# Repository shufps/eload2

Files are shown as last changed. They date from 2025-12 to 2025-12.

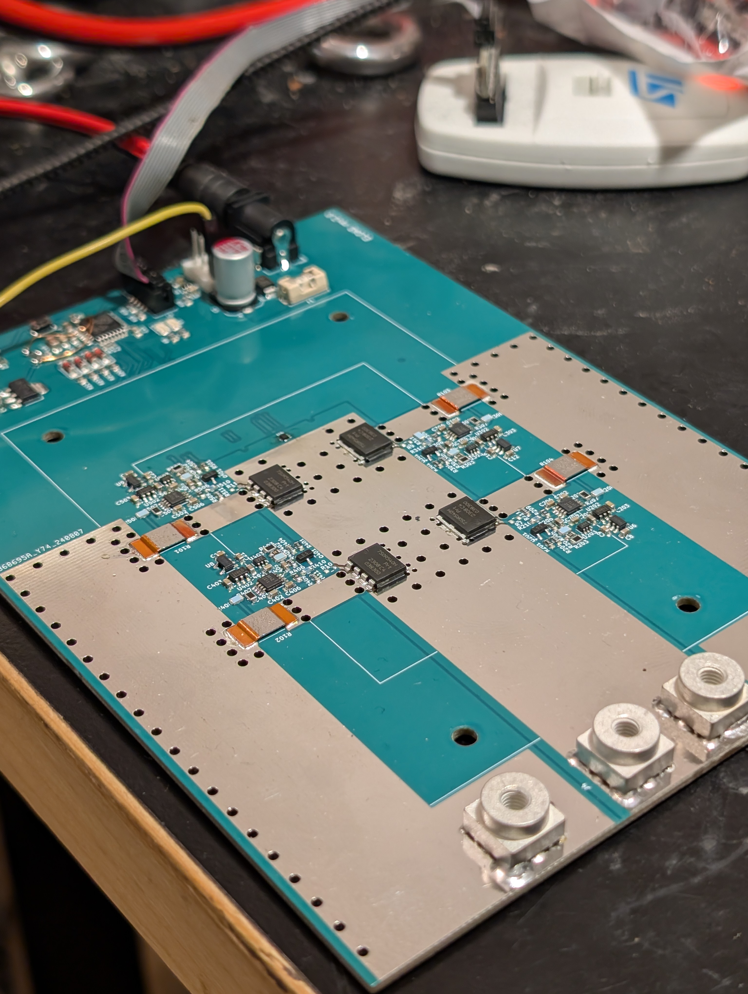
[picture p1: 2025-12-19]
images/PXL_20251215_150642152.jpg

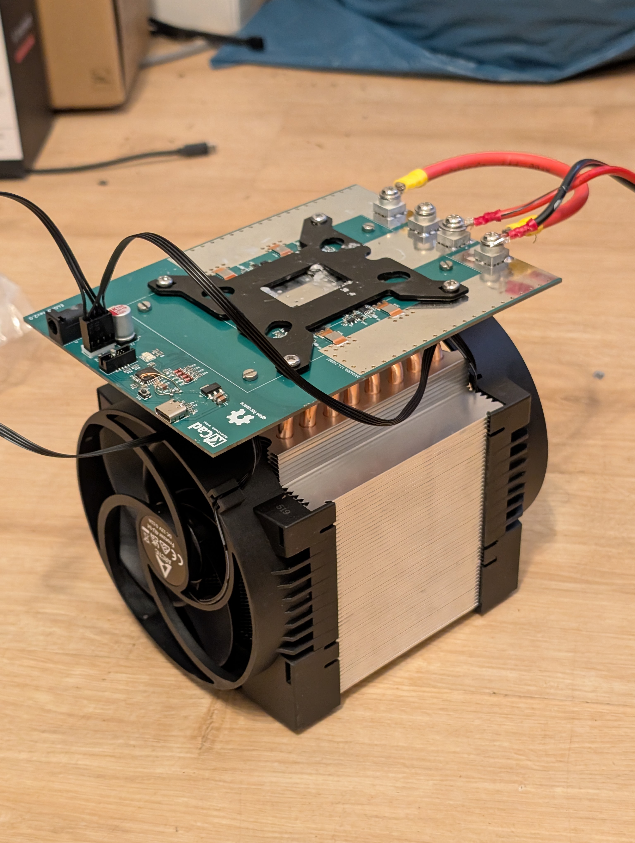
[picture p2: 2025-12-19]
images/PXL_20251219_101324146.jpg

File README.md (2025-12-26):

> ⚠️ **Disclaimer / Status**
>
> This project is provided **AS IS**, **without any warranty** and **without any kind of support**.
> Use at your own risk — this is **high-current / high-power** hardware and can damage equipment or cause injury if used incorrectly.

# eload2 (Load v2)





A compact, over-engineered **multi-channel electronic load** for **low-voltage / high-current** testing — built because nothing affordable exists that does *0–1.5V @ ~100A* properly.

No display. Control via **USB** from a PC (Python), firmware on **STM32**.

## Why this exists

I needed a tool to:
- test **buck converters / VRMs** in the **0–1.5V** range at serious currents
- still be usable as a “normal” load at **12V** (e.g. for power supplies / battery projects)
- be stable, repeatable and boring (in the good sense)

Commercial options in this niche are either impractical or unreasonably expensive — so I built it.

## Highlights

- **4 independent channels**
- Designed for:
  - **0–1.5V** VRM / buck testing up to **~100A** total (depending on cooling & SOA)
  - **12V** testing (e.g. ~8–12A, depending on dissipation)
- Each channel has its own analog supply chain (low coupling, predictable behavior):
  - dedicated **9V LDO**
  - dedicated precision **reference** (REF3433)
  - dedicated **16-bit DAC**
  - dedicated **OPA2196** control loop
  - dedicated MOSFET “arm”
- MOSFETs: **BUK7S0R5-40HJ** (very low Rds(on), beefy SOA)
- Cooling: **SP3/TR4 CPU cooler** (tested in practice)
- High-current IO: **M4** power connections (aiming for ~80A per connector)
- PCB: **120 × 160 mm**, **4-layer**, 1oz/1oz
  (large copper, parallel layers, big via arrays; optional copper busbars)

## Status

- PCBs + stencil: ✅
- Parts: ✅ (BOM originally ~1.5 years old, most parts still available)
- Bring-up: ✅
- Verified load test: **12V @ 10A (120W) for ~15 min → ~55°C board temperature** (with the big cooler)

## Errata

- Current setting is a little bit off. For example 11.5A needs to be set for 10.0A current.

## Minimalistic Web UI

There is a minimalistic web UI.



It can be run using `streamlit`:
```bash
streamlit run eload_ui.py
```

## Documentation

https://www.mikrocontroller.net/topic/563073

## Repository structure (typical)

- `kicad/` – schematics, PCB, mechanical notes
- `firmware/` – STM32 firmware (Rust, Embassy)
- `python/` – PC tooling / scripts (Python)

## Quick start

### Firmware
- Build/flash using your usual STM32 + Rust toolchain.
- This project uses **Embassy** async tasks.

### Host control
- Connect the board via USB.
- Use the Python scripts to set:
  - per-channel DAC setpoints
  - PWM / fan / enable (depending on build)
  - read back telemetry (if enabled)

## Safety / Notes

This is a **high current** design.
- Use short, thick wiring for low-voltage/high-current tests.
- Treat every milliohm as a heater.
- Ensure solid cooling and stable mounting before sustained high power tests.
- If you don’t know what you’re doing: don’t connect this to expensive hardware.

## License

CERN-OHL-S: https://ohwr.org/cern_ohl_s_v2.pdf

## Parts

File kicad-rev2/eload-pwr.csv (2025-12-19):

Reference | Value | Footprint | Qty | DNP | Distributor | Manufacturer | OrderNr
C1,C202,C204,C302,C304,C402,C404,C502,C504 | 100n | Capacitor_SMD:C_0603_1608Metric | 9
C2 | 330µ | Capacitor_SMD:CP_Elec_8x10 | 1 |  | D | A768KS337M1ELAE019 | 399-A768KS337M1ELAE019CT-ND
C3,C4,C15,C20 | 10µ/50V | Capacitor_SMD:C_1206_3216Metric | 4
C5,C14,C18,C19 | 1µ | Capacitor_SMD:C_0805_2012Metric | 4
C8,C9,C12,C16,C17,C21,C22,C23,C201,C205,C301,C305,C401,C405,C501,C505 | 1µ | Capacitor_SMD:C_0603_1608Metric | 16
C10,C11,C13 | 100n | Capacitor_SMD:C_0805_2012Metric | 3
C203,C303,C403,C503 | 10µ | Capacitor_SMD:C_0603_1608Metric | 4
C206,C306,C406,C506 | 10n | Capacitor_SMD:C_0603_1608Metric | 4
D1 | SMBJ12A | Diode_SMD:D_SMB | 1 |  | D | SMBJ12A | SMBJ12ALFCT-ND
D2,D6,D7,D8,D9 | 3.3V | Diode_SMD:D_MiniMELF | 5 |  | D | BZV55-C3V6,115 | 1727-3631-1-ND
D4 | LED | LED_SMD:LED_1206_3216Metric | 1
F1 | 0.5A | myfootprints:fuseholder_littlefuse_blok | 1 |  | D | 0154.500DR | F1220CT-ND
J1 | Barrel_Jack_Switch | Connector_BarrelJack:BarrelJack_CUI_PJ-102AH_Horizontal | 1 |  | D | PJ-102AH | CP-102AH-ND
J2 | USB_C_Receptacle_USB2.0 | Connector_USB:USB_C_Receptacle_GCT_USB4105-xx-A_16P_TopMnt_Horizontal | 1 |  | D | USB4105-GF-A | 2073-USB4105-GF-ACT-ND
J3 | SWD | myfootprints:PinHeader_IDC_2x05_P1.27mm_Vertical_SMD | 1 |  | X
J4,J5,J6,J7 | Conn_01x01 | TerminalBlock_Wuerth:Wuerth_REDCUBE-THR_WP-THRBU_74650194_THR | 4 |  | D | 74650194R | 732-74650194RCT-ND
M1 | Fan_4pin | Connector:FanPinHeader_1x04_P2.54mm_Vertical | 1 |  | D | 0470531000 | WM4330-ND
Q101,Q102,Q103,Q104 | NMOS | myfootprints:LFPAK88-SOT1235 | 4 |  | D | BUK7S0R5-40HJ | 1727-BUK7S0R5-40HJCT-ND
Q201,Q301,Q401,Q501 | BSS138 | Package_TO_SOT_SMD:SOT-23 | 4 |  | D | BSS138 | 4530-BSS138CT-ND
R1,R2 | 5.1k | Resistor_SMD:R_0805_2012Metric | 2
R3,R4,R14 | 22 | Resistor_SMD:R_0805_2012Metric | 3
R5 | 100k | Resistor_SMD:R_0805_2012Metric | 1
R6,R18 | 3.3k | Resistor_SMD:R_0805_2012Metric | 2
R7,R9,R10,R11 | 100k | Resistor_SMD:R_0603_1608Metric | 4
R8 | 560 | Resistor_SMD:R_0805_2012Metric | 1
R12,R15,R16,R17 | 10k | Resistor_SMD:R_0805_2012Metric | 4
R13 | 33k | Resistor_SMD:R_0805_2012Metric | 1
R19 | 2.7k | Resistor_SMD:R_0805_2012Metric | 1
R20,R21,R22,R23 | 1.5k | Resistor_SMD:R_0805_2012Metric | 4
R101,R102,R103,R104 | 4m/4W/0.5% | myfootprints:R3920 | 4 |  | D | SEWF3920D4L00P9 | 4506-SEWF3920D4L00P9CT-ND
R201,R301,R401,R501 | 17.4k | Resistor_SMD:R_0603_1608Metric | 4
R202,R302,R402,R502 | 10k | Resistor_SMD:R_0603_1608Metric | 4
R203,R207,R303,R307,R403,R407,R503,R507 | 31.6k/0.1% | Resistor_SMD:R_0603_1608Metric | 8 |  | D | RG2012P-3162-B-T5 | RG20P31.6KBCT-ND
R204,R206,R211,R304,R306,R311,R404,R406,R411,R504,R506,R511 | 1k | Resistor_SMD:R_0603_1608Metric | 12
R205,R208,R305,R308,R405,R408,R505,R508 | 1k/0.1% | Resistor_SMD:R_0603_1608Metric | 8 |  | D | RG2012P-102-B-T5 | RG20P1.0KBCT-ND
R209,R309,R409,R509 | 0R | Resistor_SMD:R_0603_1608Metric | 4
R210,R310,R410,R510 | 100 | Resistor_SMD:R_0603_1608Metric | 4
SW1 | boot | Button_Switch_SMD:SW_Push_1P1T_NO_CK_KMR2 | 1 |  | D | KMR231NG ULC LFS | CKN10284CT-ND
U1 | LM1117-3.3 | Package_TO_SOT_SMD:SOT-223-3_TabPin2 | 1 |  | D | LM1117MPX-33NOPB | 488-LM1117MPX-33NOPBCT-ND
U2 | STM32L072KZT6 | Package_QFP:LQFP-32_7x7mm_P0.8mm | 1 |  | D | STM32L072KZT6 | 497-19668-ND
U4 | TMP1075 | myfootprints:TMP1075-DRL | 1 |  | D | TMP1075NDRLR | 296-TMP1075NDRLRCT-ND
U5 | TXU0101 | Package_TO_SOT_SMD:SOT-363_SC-70-6 | 1 |  | D | TXU0101DCKR | 296-TXU0101DCKRCT-ND
U6,U7,U8,U9 | R1154N090B | Package_TO_SOT_SMD:SOT-23-5 | 4 |  | D | R1154N090B-TR-FE | 2129-R1154N090B-TR-FECT-ND
U201,U301,U401,U501 | OPA2196IDGKT | Package_SO:VSSOP-8_3.0x3.0mm_P0.65mm | 4 |  | D | OPA2196IDGKT | 296-48158-1-ND
U202,U302,U402,U502 | REF3433IDBVR | Package_TO_SOT_SMD:SOT-23-6 | 4 |  | D | REF3433IDBVR | 296-49859-1-ND
U203,U303,U403,U503 | DAC8411IDCKR | Package_TO_SOT_SMD:SOT-363_SC-70-6 | 4 |  | D | DAC8411IDCKR | 296-DAC8411IDCKRCT-ND

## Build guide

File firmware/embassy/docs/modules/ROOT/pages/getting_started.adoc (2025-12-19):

= Getting started

So you want to try Embassy, great! To get started, there are a few tools you need to install:

* link:https://rustup.rs/[rustup] - the Rust toolchain is needed to compile Rust code.
* link:https://crates.io/crates/probe-rs[probe-rs] - to flash the firmware on your device. If you already have other tools like `OpenOCD` setup, you can use that as well.

If you don't have any supported board, don't worry: you can also run embassy on your PC using the `std` examples.

== Getting a board with examples

Embassy supports many microcontroller families, but the quickest way to get started is by using a board which Embassy has existing example code for.

This list is non-exhaustive. If your board isn’t included here, check the link:https://github.com/embassy-rs/embassy/tree/main/examples[examples folder] to see if example code has been written for it.

=== nRF kits

* link:https://www.nordicsemi.com/Products/Development-hardware/nrf52-dk[nRF52 DK]
* link:https://www.nordicsemi.com/Products/Development-hardware/nRF9160-DK[nRF9160 DK]

=== STM32 kits

* link:https://www.st.com/en/evaluation-tools/nucleo-h743zi.html[STM32 Nucleo-144 development board with STM32H743ZI MCU]
* link:https://www.st.com/en/evaluation-tools/nucleo-f429zi.html[STM32 Nucleo-144 development board with STM32F429ZI MCU]
* link:https://www.st.com/en/evaluation-tools/b-l4s5i-iot01a.html[STM32L4+ Discovery kit IoT node, low-power wireless, BLE, NFC, WiFi]
* link:https://www.st.com/en/evaluation-tools/b-l072z-lrwan1.html[STM32L0 Discovery kit LoRa, Sigfox, low-power wireless]
* link:https://www.st.com/en/evaluation-tools/nucleo-wl55jc.html[STM32 Nucleo-64 development board with STM32WL55JCI MCU]
* link:https://www.st.com/en/evaluation-tools/b-u585i-iot02a.html[Discovery kit for IoT node with STM32U5 series]

=== RP2040 kits

* link:https://www.raspberrypi.com/products/raspberry-pi-pico/[Raspberry Pi Pico]

=== ESP32

* link:https://github.com/esp-rs/esp-rust-board[ESP32C3]

== Running an example

First you need to clone the link:https://github.com/embassy-rs/embassy[github repository];

[source, bash]
----
git clone https://github.com/embassy-rs/embassy.git
cd embassy
----

Once you have a copy of the repository, find examples folder for your board and, and build an example program. `blinky` is a good choice as all it does is blink an LED – the embedded world’s equivalent of “Hello World”.

[source, bash]
----
cd examples/nrf52840
cargo build --bin blinky --release
----

Once you’ve confirmed you can build the example, connect your computer to your board with a debug probe and run it on hardware:

[source, bash]
----
cargo run --bin blinky --release
----

If everything worked correctly, you should see a blinking LED on your board, and debug output similar to this on your computer:

[source]
----
    Finished dev [unoptimized + debuginfo] target(s) in 1m 56s
     Running `probe-run --chip STM32F407VGTx target/thumbv7em-none-eabi/debug/blinky`
(HOST) INFO  flashing program (71.36 KiB)
(HOST) INFO  success!
────────────────────────────────────────────────────────────────────────────────
0 INFO  Hello World!
└─ blinky::__embassy_main::task::{generator#0} @ src/bin/blinky.rs:18
1 INFO  high
└─ blinky::__embassy_main::task::{generator#0} @ src/bin/blinky.rs:23
2 INFO  low
└─ blinky::__embassy_main::task::{generator#0} @ src/bin/blinky.rs:27
3 INFO  high
└─ blinky::__embassy_main::task::{generator#0} @ src/bin/blinky.rs:23
4 INFO  low
└─ blinky::__embassy_main::task::{generator#0} @ src/bin/blinky.rs:27
----

NOTE: How does the `cargo run` command know how to connect to our board and program it? In each `examples` folder, there’s a `.cargo/config.toml` file which tells cargo to use link:https://probe.rs/[probe-rs] as the runner for ARM binaries in that folder. probe-rs handles communication with the debug probe and MCU. In order for this to work, probe-rs needs to know which chip it’s programming, so you’ll have to edit this file if you want to run examples on other chips.

=== It didn’t work!

If you hare having issues when running `cargo run --release`, please check the following:

* You are specifying the correct `--chip` on the command line, OR
* You have set `.cargo/config.toml`'s run line to the correct chip, AND
* You have changed `examples/Cargo.toml`'s HAL (e.g. embassy-stm32) dependency's feature to use the correct chip (replace the existing stm32xxxx feature)

At this point the project should run. If you do not see a blinky LED for blinky, for example, be sure to check the code is toggling your board's LED pin.

If you are trying to run an example with `cargo run --release` and you see the following output:
[source]
----
0.000000 INFO Hello World!
└─ <invalid location: defmt frame-index: 14>
0.000000 DEBUG rcc: Clocks { sys: Hertz(80000000), apb1: Hertz(80000000), apb1_tim: Hertz(80000000), apb2: Hertz(80000000), apb2_tim: Hertz(80000000), ahb1: Hertz(80000000), ahb2: Hertz(80000000), ahb3: Hertz(80000000) }
└─ <invalid location: defmt frame-index: 124>
0.000061 TRACE allocating type=Interrupt mps=8 interval_ms=255, dir=In
└─ <invalid location: defmt frame-index: 68>
0.000091 TRACE   index=1
└─ <invalid location: defmt frame-index: 72>
----

To get rid of the frame-index error add the following to your `Cargo.toml`:

[source,toml]
----
[profile.release]
debug = 2
----

If you’re still having problems, check the link:https://embassy.dev/book/dev/faq.html[FAQ], or ask for help in the link:https://matrix.to/#/#embassy-rs:matrix.org[Embassy Chat Room].

== What's next?

Congratulations, you have your first Embassy application running! Here are some suggestions for where to go from here:

* Read more about the xref:runtime.adoc[executor].
* Read more about the xref:hal.adoc[HAL].
* Start xref:basic_application.adoc[writing your application].

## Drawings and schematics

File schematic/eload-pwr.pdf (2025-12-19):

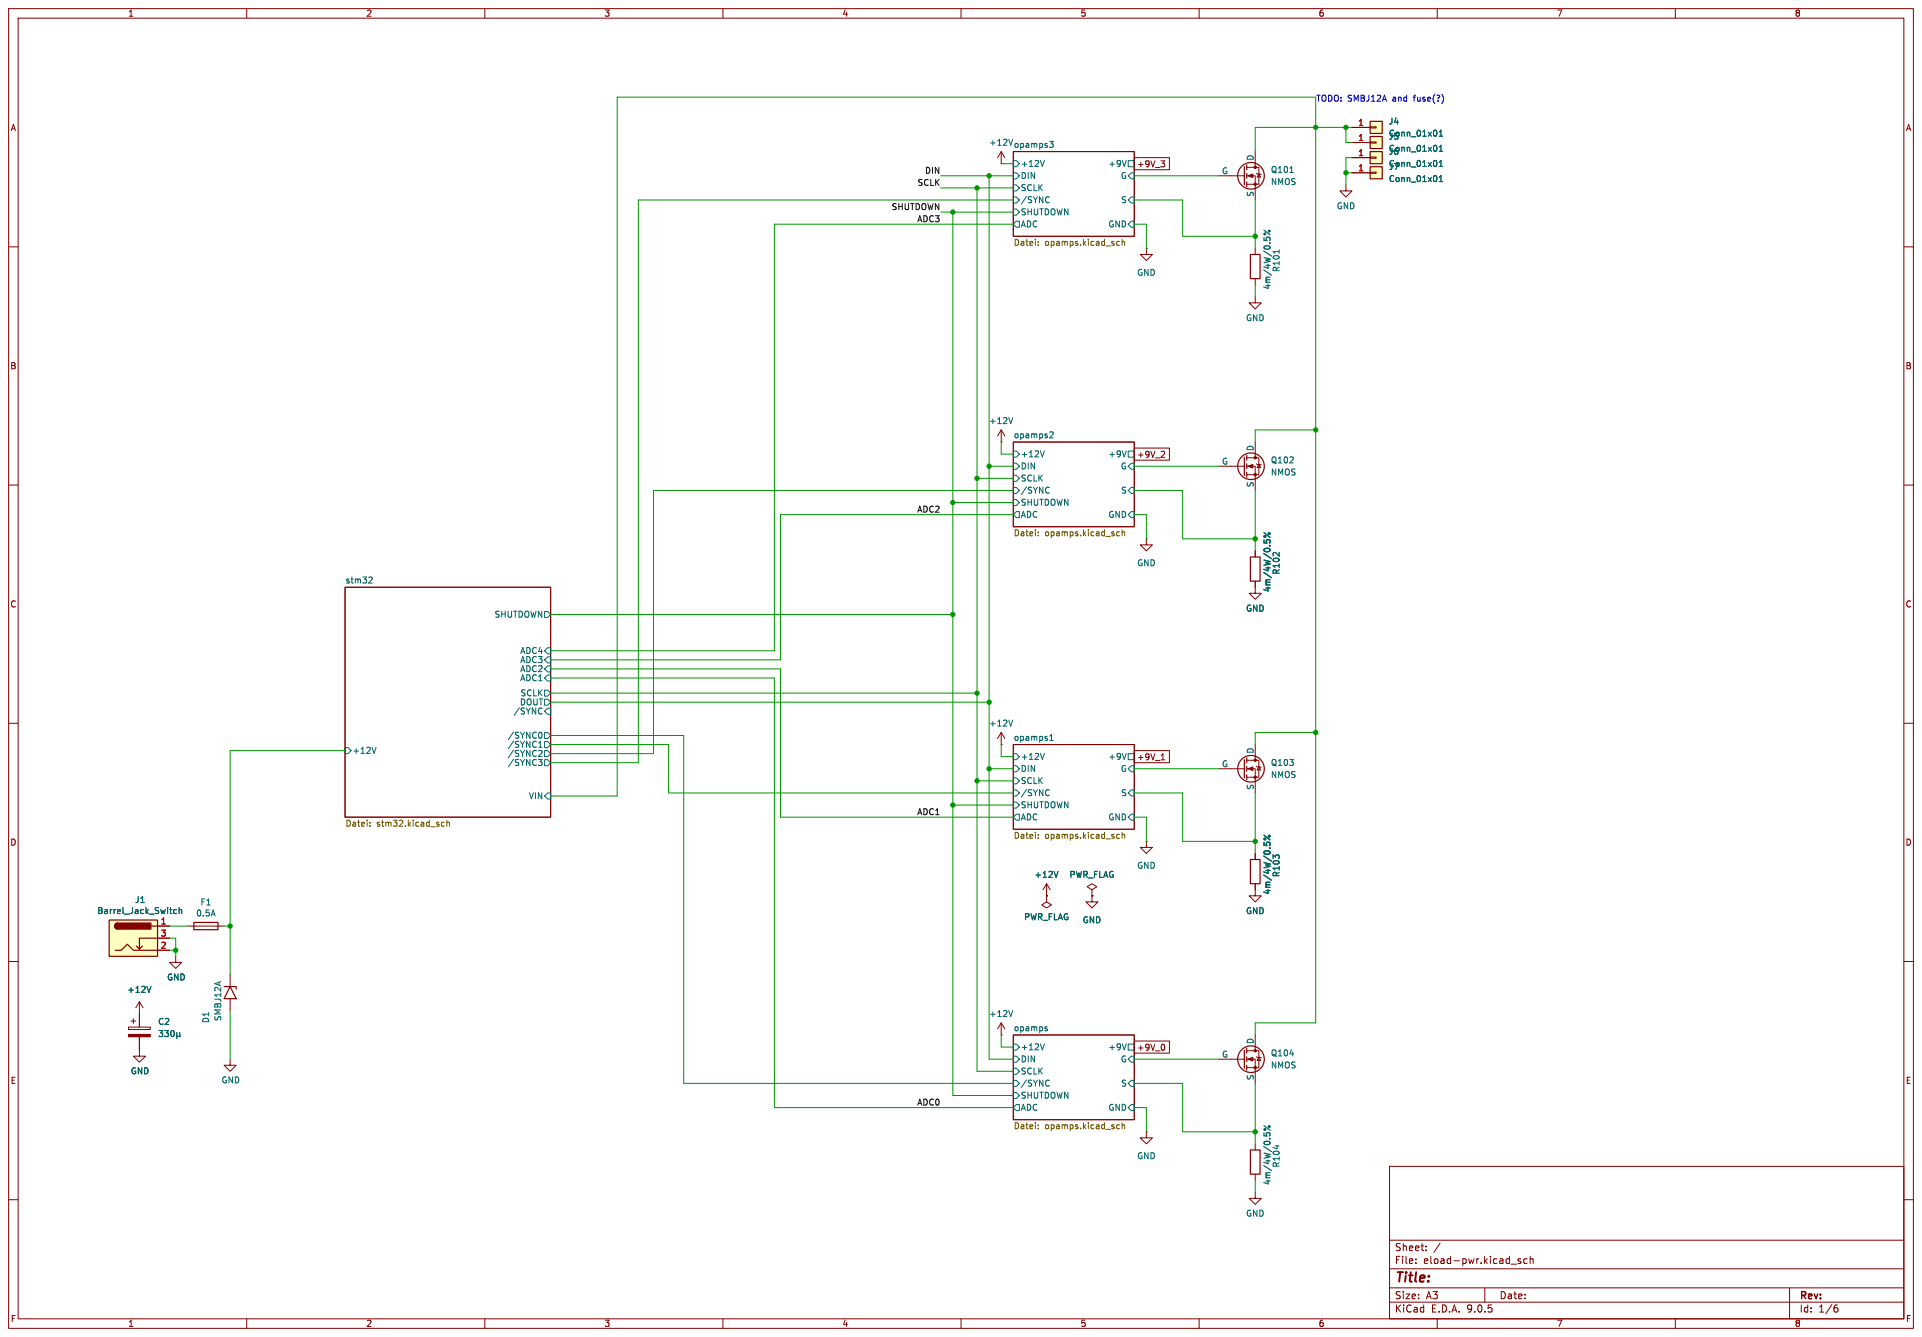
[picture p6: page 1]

Id: 1/6 Title: File: eload-pwr.kicad_sch Sheet: /

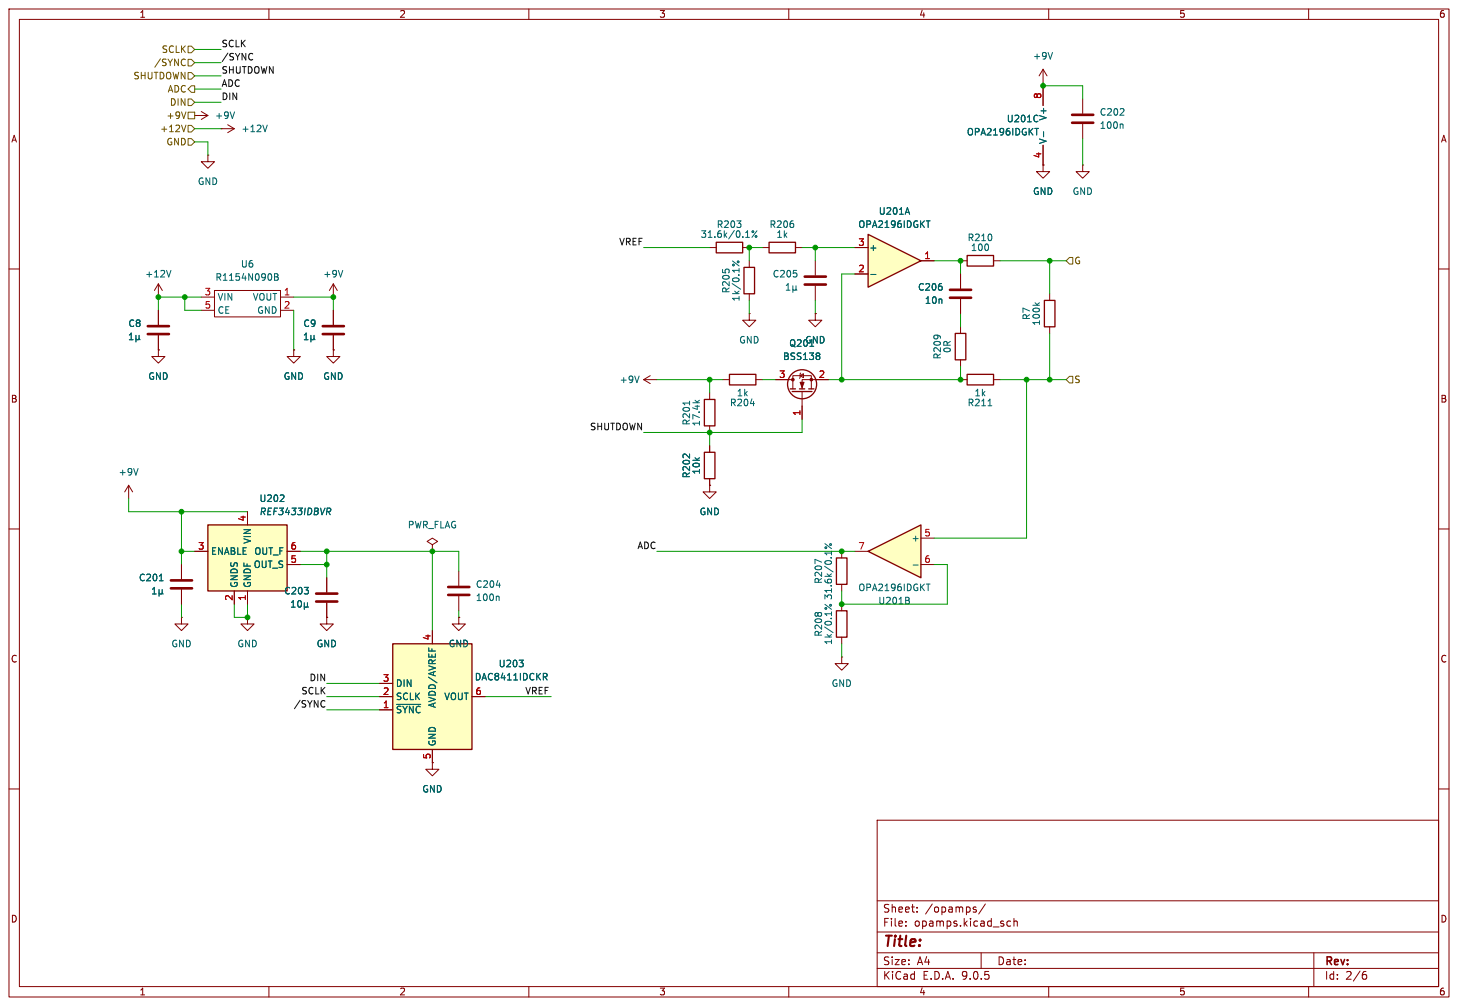
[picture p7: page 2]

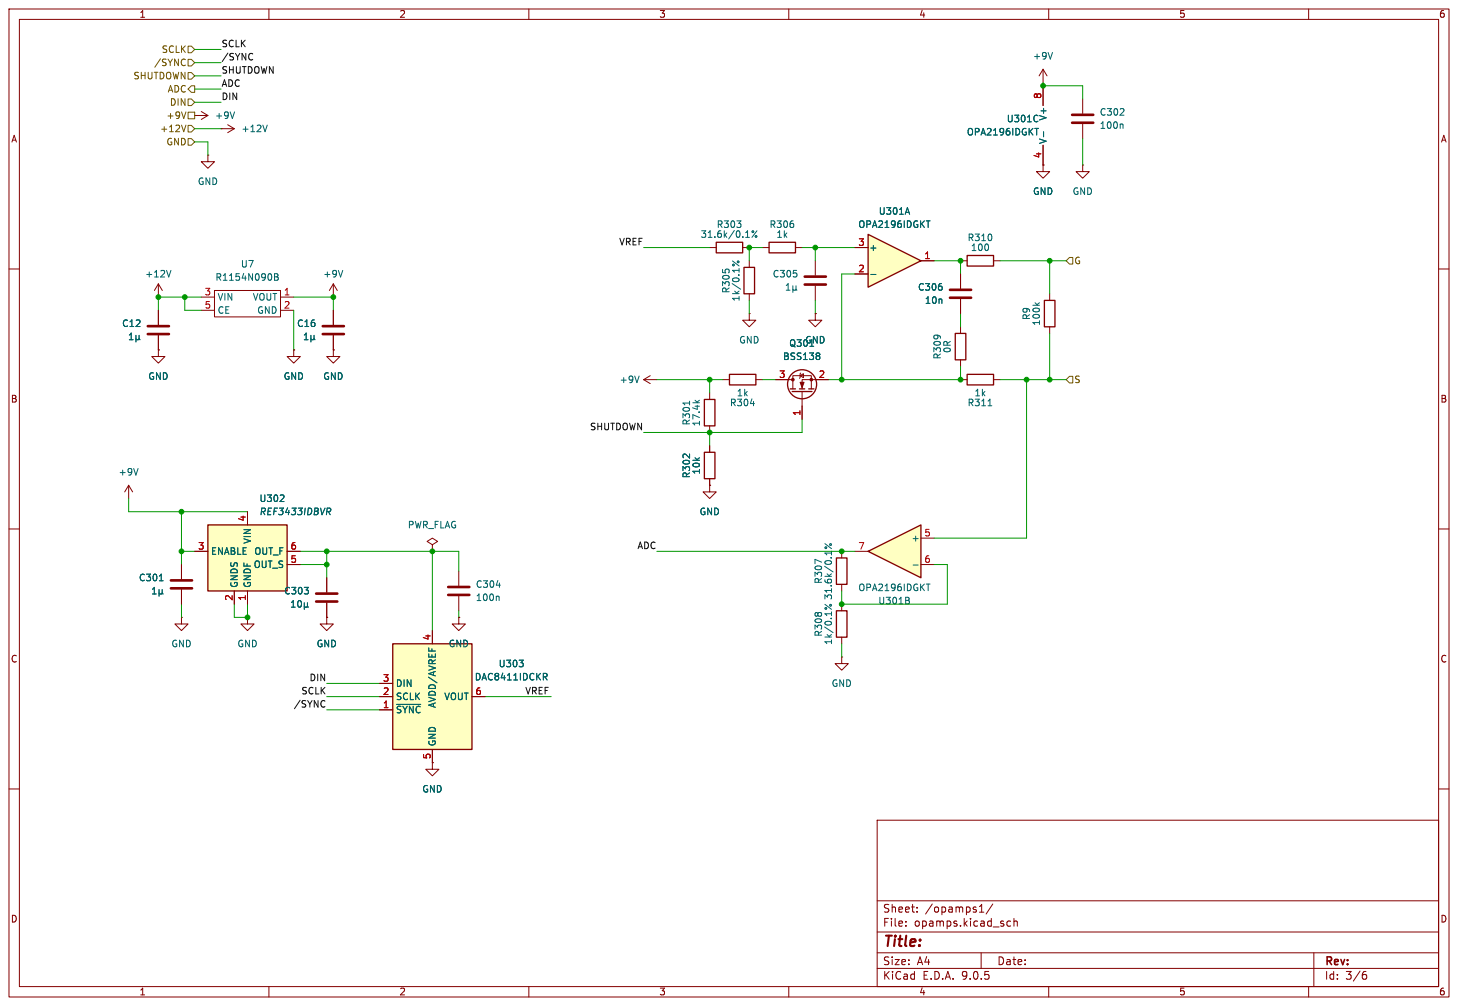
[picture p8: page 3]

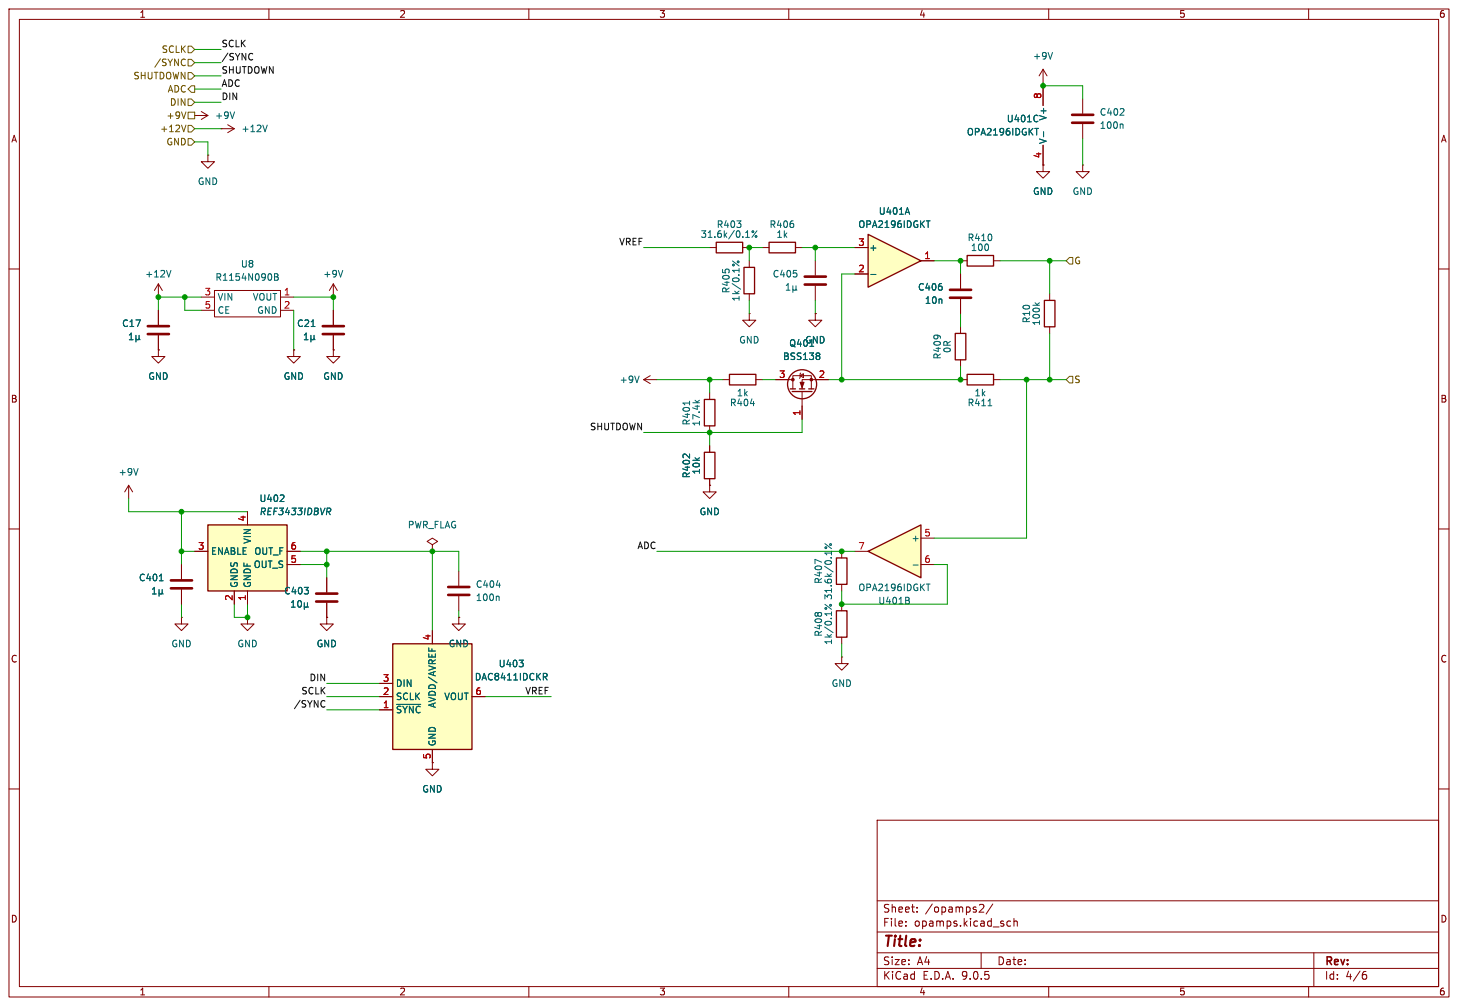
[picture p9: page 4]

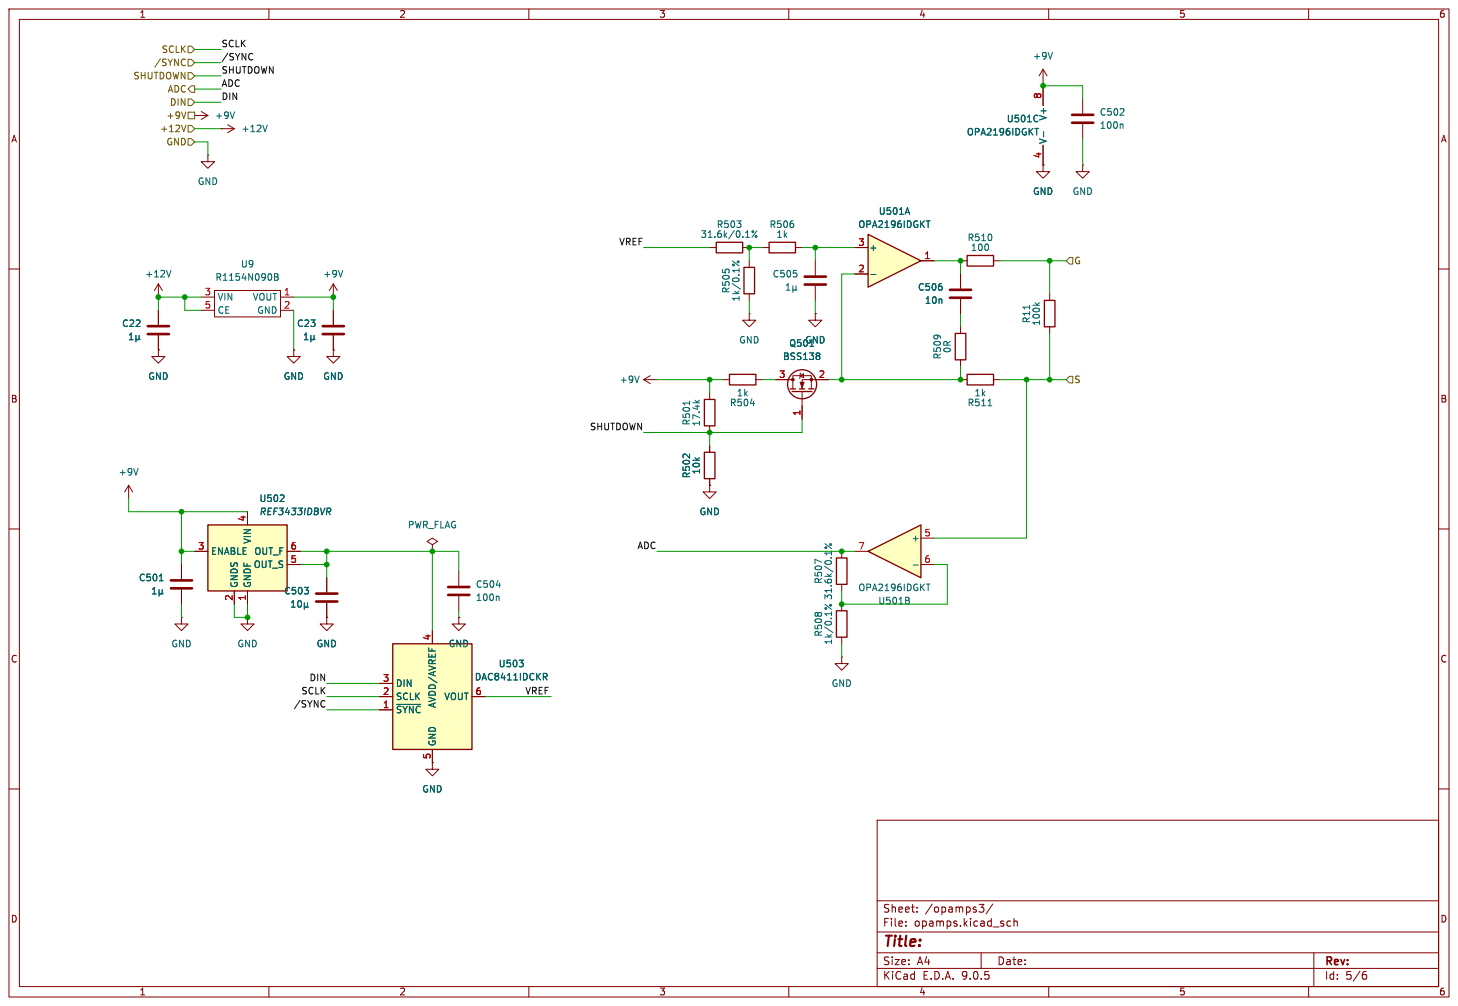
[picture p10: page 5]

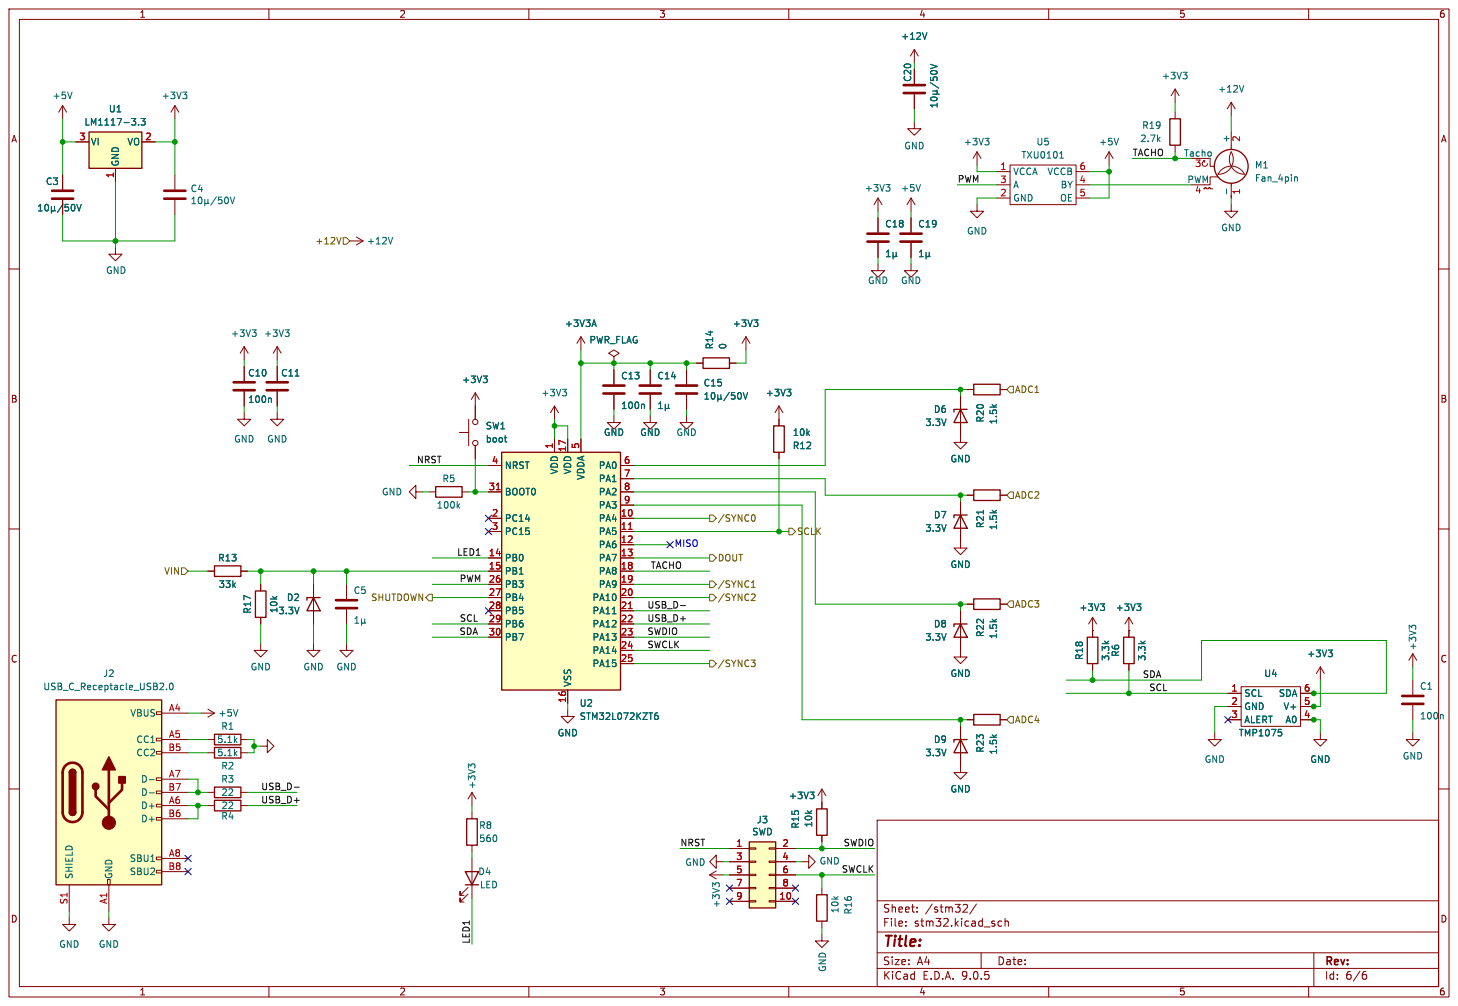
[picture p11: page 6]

Id: 6/6 Title: File: stm32.kicad_sch Sheet: /stm32/ D8

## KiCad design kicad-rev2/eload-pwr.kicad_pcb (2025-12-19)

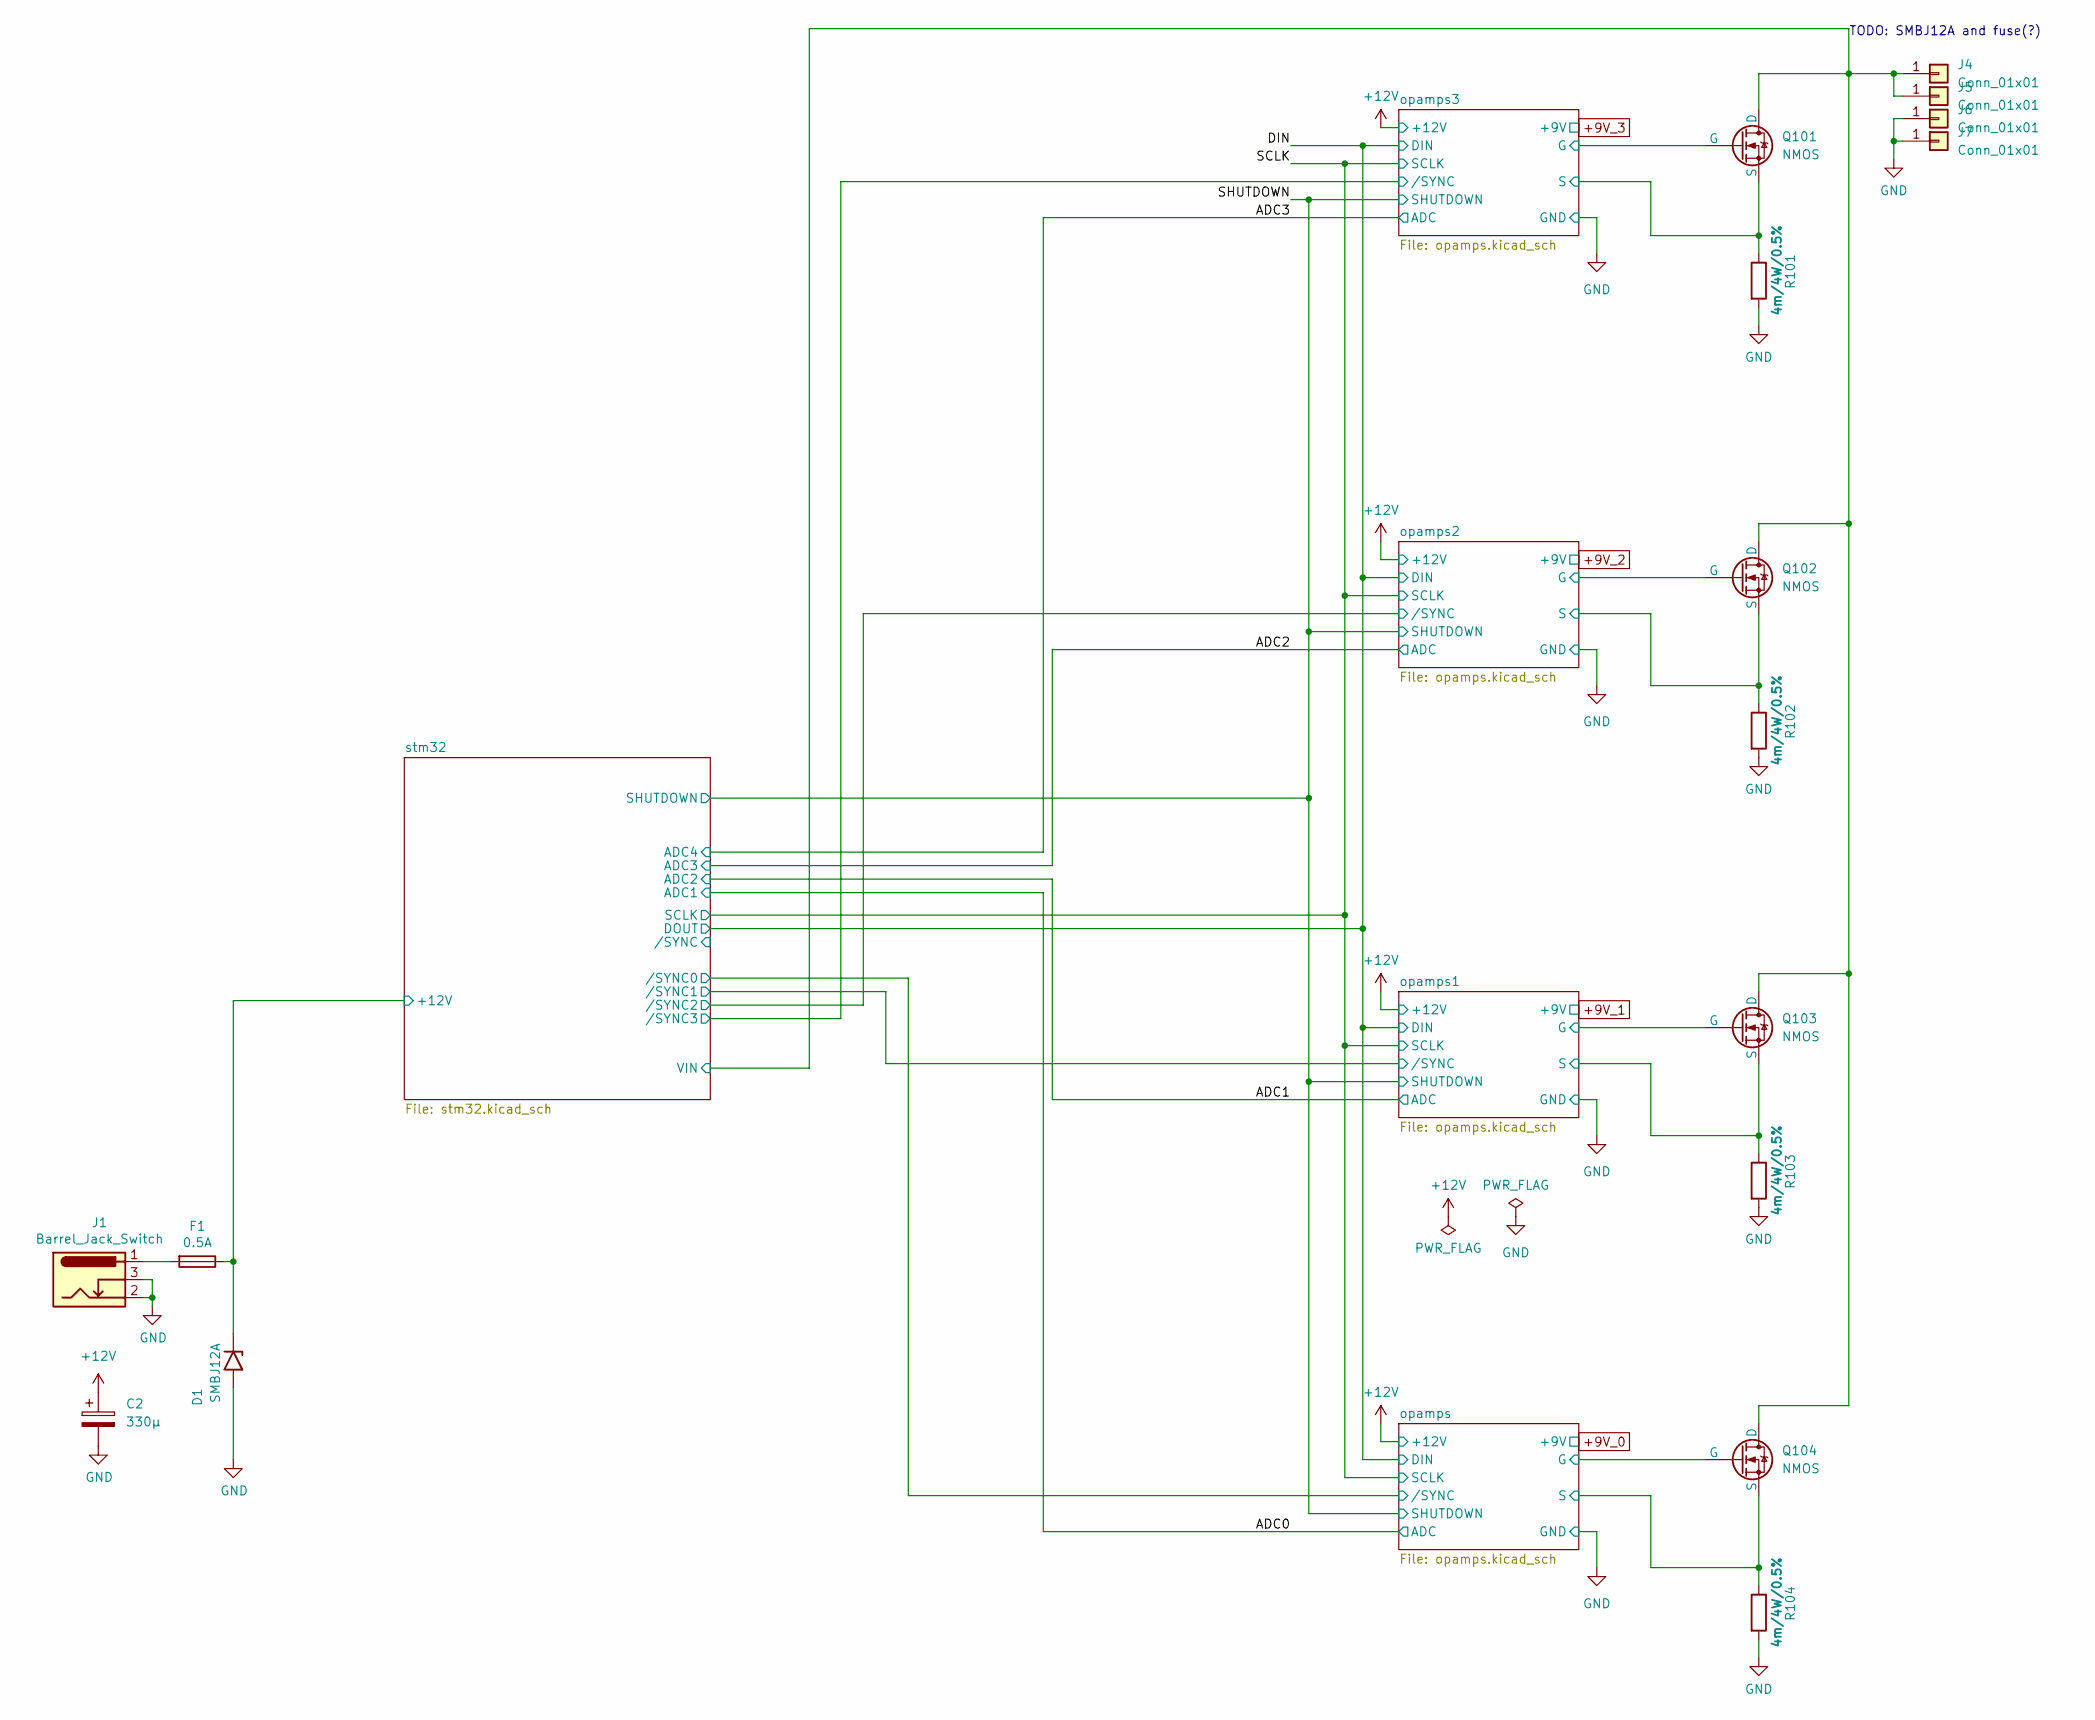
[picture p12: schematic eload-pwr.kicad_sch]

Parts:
C2: 330µ; CP_Elec_8x10
D1: SMBJ12A; D_SMB
F1: 0.5A; fuseholder_littlefuse_blok
J1: Barrel_Jack_Switch; BarrelJack_CUI_PJ-102AH_Horizontal
J4, J5, J6, J7: Conn_01x01; Wuerth_REDCUBE-THR_WP-THRBU_74650194_THR
Q101, Q102, Q103, Q104: NMOS; LFPAK88-SOT1235
R101, R102, R103, R104: 4m/4W/0.5%; R3920

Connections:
+12V: C2.1, D1.1 (A1), F1.1; also elsewhere on the board
/opamps1/G: Q103.G; also elsewhere on the board
/opamps1/S: Q103.S, R103.1; also elsewhere on the board
/opamps2/G: Q102.G; also elsewhere on the board
/opamps2/S: Q102.S, R102.1; also elsewhere on the board
/opamps3/G: Q101.G; also elsewhere on the board
/opamps3/S: Q101.S, R101.1; also elsewhere on the board
/opamps/G: Q104.G; also elsewhere on the board
/opamps/S: Q104.S, R104.1; also elsewhere on the board
/stm32/VIN: J4.1, J5.1, Q101.D, Q102.D, Q103.D, Q104.D; also elsewhere on the board
GND: C2.2, D1.2 (A2), J1.2, J1.3, J6.1, J7.1, R101.2, R102.2, R103.2, R104.2; also elsewhere on the board
unnamed: F1.2, J1.1

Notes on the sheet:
TODO: SMBJ12A and fuse(?)

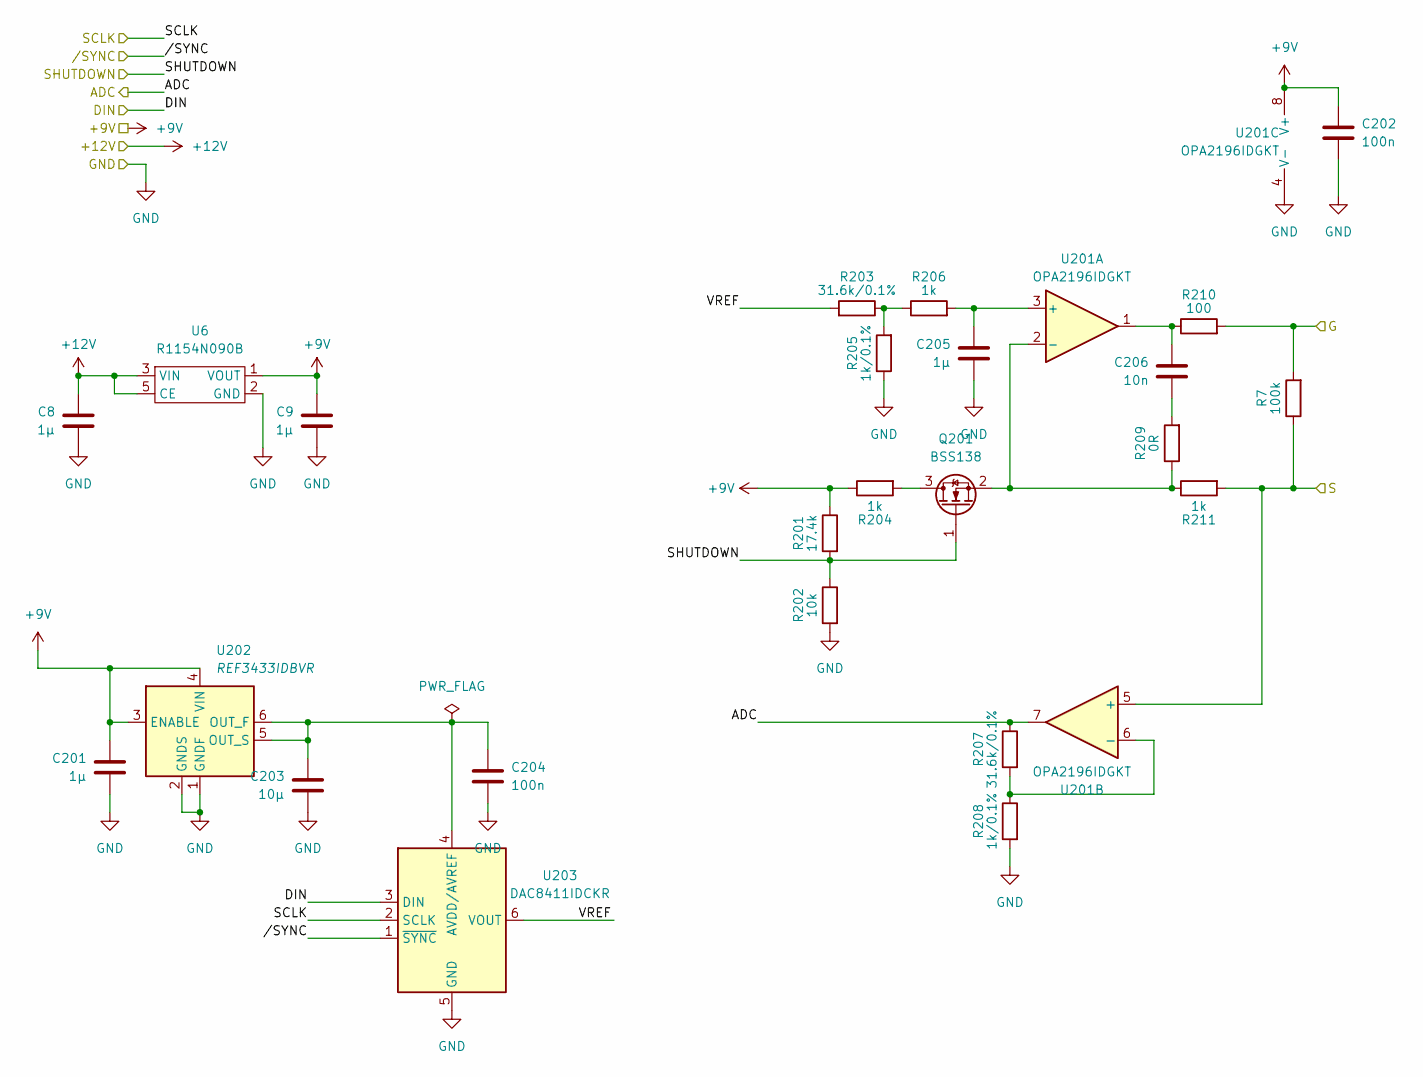
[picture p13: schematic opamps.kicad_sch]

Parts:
C8, C9, C201, C205: 1µ; C_0603_1608Metric
C202, C204: 100n; C_0603_1608Metric
C203: 10µ; C_0603_1608Metric
C206: 10n; C_0603_1608Metric
Q201: BSS138; SOT-23
R7: 100k; R_0603_1608Metric
R201: 17.4k; R_0603_1608Metric
R202: 10k; R_0603_1608Metric
R203, R207: 31.6k/0.1%; R_0603_1608Metric
R204, R206, R211: 1k; R_0603_1608Metric
R205, R208: 1k/0.1%; R_0603_1608Metric
R209: 0R; R_0603_1608Metric
R210: 100; R_0603_1608Metric
U6: R1154N090B; SOT-23-5
U201: OPA2196IDGKT; VSSOP-8_3.0x3.0mm_P0.65mm
U202: REF3433IDBVR; SOT-23-6
U203: DAC8411IDCKR; SOT-363_SC-70-6

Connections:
+9V_0: C9.1, C201.1, C202.1, R201.1, R204.1, U6.1 (VOUT), U201.8 (V+), U202.3 (ENABLE), U202.4 (VIN)
+12V: C8.1, U6.3 (VIN), U6.5 (CE); also elsewhere on the board
/ADC0: R207.1, U201.7; also elsewhere on the board
/DIN: U203.3 (DIN); also elsewhere on the board
/SCLK: U203.2 (SCLK); also elsewhere on the board
/SHUTDOWN: Q201.1 (G), R201.2, R202.1; also elsewhere on the board
/opamps/G: R7.2, R210.2; also elsewhere on the board
/opamps/S: R7.1, R211.2, U201.5 (+); also elsewhere on the board
/opamps/VREF: R203.2, U203.6 (VOUT)
/opamps//SYNC: U203.1 (~SYNC); also elsewhere on the board
GND: C8.2, C9.2, C201.2, C202.2, C203.2, C204.2, C205.2, R202.2, R205.1, R208.2, U6.2 (GND), U201.4 (V-), U202.1 (GNDF), U202.2 (GNDS), U203.5 (GND); also elsewhere on the board
unnamed: C206.1, R210.1, U201.1
unnamed: C206.2, R209.2
unnamed: Q201.3 (D), R204.2
unnamed: Q201.2 (S), R209.1, R211.1, U201.2 (-)
unnamed: R203.1, R205.2, R206.1
unnamed: C205.1, R206.2, U201.3 (+)
unnamed: R207.2, R208.1, U201.6 (-)
unnamed: C203.1, C204.1, U202.5 (OUT_S), U202.6 (OUT_F), U203.4 (AVDD/AVREF)

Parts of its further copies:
C12, C16, C17, C21, C22, C23, C301, C305, C401, C405, C501, C505: 1µ; C_0603_1608Metric
C302, C304, C402, C404, C502, C504: 100n; C_0603_1608Metric
C303, C403, C503: 10µ; C_0603_1608Metric
C306, C406, C506: 10n; C_0603_1608Metric
Q301, Q401, Q501: BSS138; SOT-23
R9, R10, R11: 100k; R_0603_1608Metric
R301, R401, R501: 17.4k; R_0603_1608Metric
R302, R402, R502: 10k; R_0603_1608Metric
R303, R307, R403, R407, R503, R507: 31.6k/0.1%; R_0603_1608Metric
R304, R306, R311, R404, R406, R411, R504, R506, R511: 1k; R_0603_1608Metric
R305, R308, R405, R408, R505, R508: 1k/0.1%; R_0603_1608Metric
R309, R409, R509: 0R; R_0603_1608Metric
R310, R410, R510: 100; R_0603_1608Metric
U7, U8, U9: R1154N090B; SOT-23-5
U301, U401, U501: OPA2196IDGKT; VSSOP-8_3.0x3.0mm_P0.65mm
U302, U402, U502: REF3433IDBVR; SOT-23-6
U303, U403, U503: DAC8411IDCKR; SOT-363_SC-70-6

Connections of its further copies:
+9V_1: C16.1, C301.1, C302.1, R301.1, R304.1, U7.1 (VOUT), U301.8 (V+), U302.3 (ENABLE), U302.4 (VIN)
+9V_2: C21.1, C401.1, C402.1, R401.1, R404.1, U8.1 (VOUT), U401.8 (V+), U402.3 (ENABLE), U402.4 (VIN)
+9V_3: C23.1, C501.1, C502.1, R501.1, R504.1, U9.1 (VOUT), U501.8 (V+), U502.3 (ENABLE), U502.4 (VIN)
+12V: C12.1, C17.1, C22.1, U7.3 (VIN), U7.5 (CE), U8.3 (VIN), U8.5 (CE), U9.3 (VIN), U9.5 (CE); also elsewhere on the board
/ADC1: R307.1, U301.7; also elsewhere on the board
/ADC2: R407.1, U401.7; also elsewhere on the board
/ADC3: R507.1, U501.7; also elsewhere on the board
/DIN: U303.3 (DIN), U403.3 (DIN), U503.3 (DIN); also elsewhere on the board
/SCLK: U303.2 (SCLK), U403.2 (SCLK), U503.2 (SCLK); also elsewhere on the board
/SHUTDOWN: Q301.1 (G), Q401.1 (G), Q501.1 (G), R301.2, R302.1, R401.2, R402.1, R501.2, R502.1; also elsewhere on the board
/opamps1/G: R9.2, R310.2; also elsewhere on the board
/opamps1/S: R9.1, R311.2, U301.5 (+); also elsewhere on the board
/opamps1/VREF: R303.2, U303.6 (VOUT)
/opamps1//SYNC: U303.1 (~SYNC); also elsewhere on the board
/opamps2/G: R10.2, R410.2; also elsewhere on the board
/opamps2/S: R10.1, R411.2, U401.5 (+); also elsewhere on the board
/opamps2/VREF: R403.2, U403.6 (VOUT)
/opamps2//SYNC: U403.1 (~SYNC); also elsewhere on the board
/opamps3/G: R11.2, R510.2; also elsewhere on the board
/opamps3/S: R11.1, R511.2, U501.5 (+); also elsewhere on the board
/opamps3/VREF: R503.2, U503.6 (VOUT)
/opamps3//SYNC: U503.1 (~SYNC); also elsewhere on the board
GND: C12.2, C16.2, C17.2, C21.2, C22.2, C23.2, C301.2, C302.2, C303.2, C304.2, C305.2, C401.2, C402.2, C403.2, C404.2, C405.2, C501.2, C502.2, C503.2, C504.2, C505.2, R302.2, R305.1, R308.2, R402.2, R405.1, R408.2, R502.2, R505.1, R508.2, U7.2 (GND), U8.2 (GND), U9.2 (GND), U301.4 (V-), U302.1 (GNDF), U302.2 (GNDS), U303.5 (GND), U401.4 (V-), U402.1 (GNDF), U402.2 (GNDS), U403.5 (GND), U501.4 (V-), U502.1 (GNDF), U502.2 (GNDS), U503.5 (GND); also elsewhere on the board
unnamed: C306.1, R310.1, U301.1
unnamed: C306.2, R309.2
unnamed: C406.1, R410.1, U401.1
unnamed: C406.2, R409.2
unnamed: C506.1, R510.1, U501.1
unnamed: C506.2, R509.2
unnamed: Q301.3 (D), R304.2
unnamed: Q301.2 (S), R309.1, R311.1, U301.2 (-)
unnamed: Q401.3 (D), R404.2
unnamed: Q401.2 (S), R409.1, R411.1, U401.2 (-)
unnamed: Q501.3 (D), R504.2
unnamed: Q501.2 (S), R509.1, R511.1, U501.2 (-)
unnamed: R303.1, R305.2, R306.1
unnamed: R403.1, R405.2, R406.1
unnamed: R503.1, R505.2, R506.1
unnamed: C305.1, R306.2, U301.3 (+)
unnamed: R307.2, R308.1, U301.6 (-)
unnamed: C303.1, C304.1, U302.5 (OUT_S), U302.6 (OUT_F), U303.4 (AVDD/AVREF)
unnamed: C405.1, R406.2, U401.3 (+)
unnamed: R407.2, R408.1, U401.6 (-)
unnamed: C403.1, C404.1, U402.5 (OUT_S), U402.6 (OUT_F), U403.4 (AVDD/AVREF)
unnamed: C505.1, R506.2, U501.3 (+)
unnamed: R507.2, R508.1, U501.6 (-)
unnamed: C503.1, C504.1, U502.5 (OUT_S), U502.6 (OUT_F), U503.4 (AVDD/AVREF)

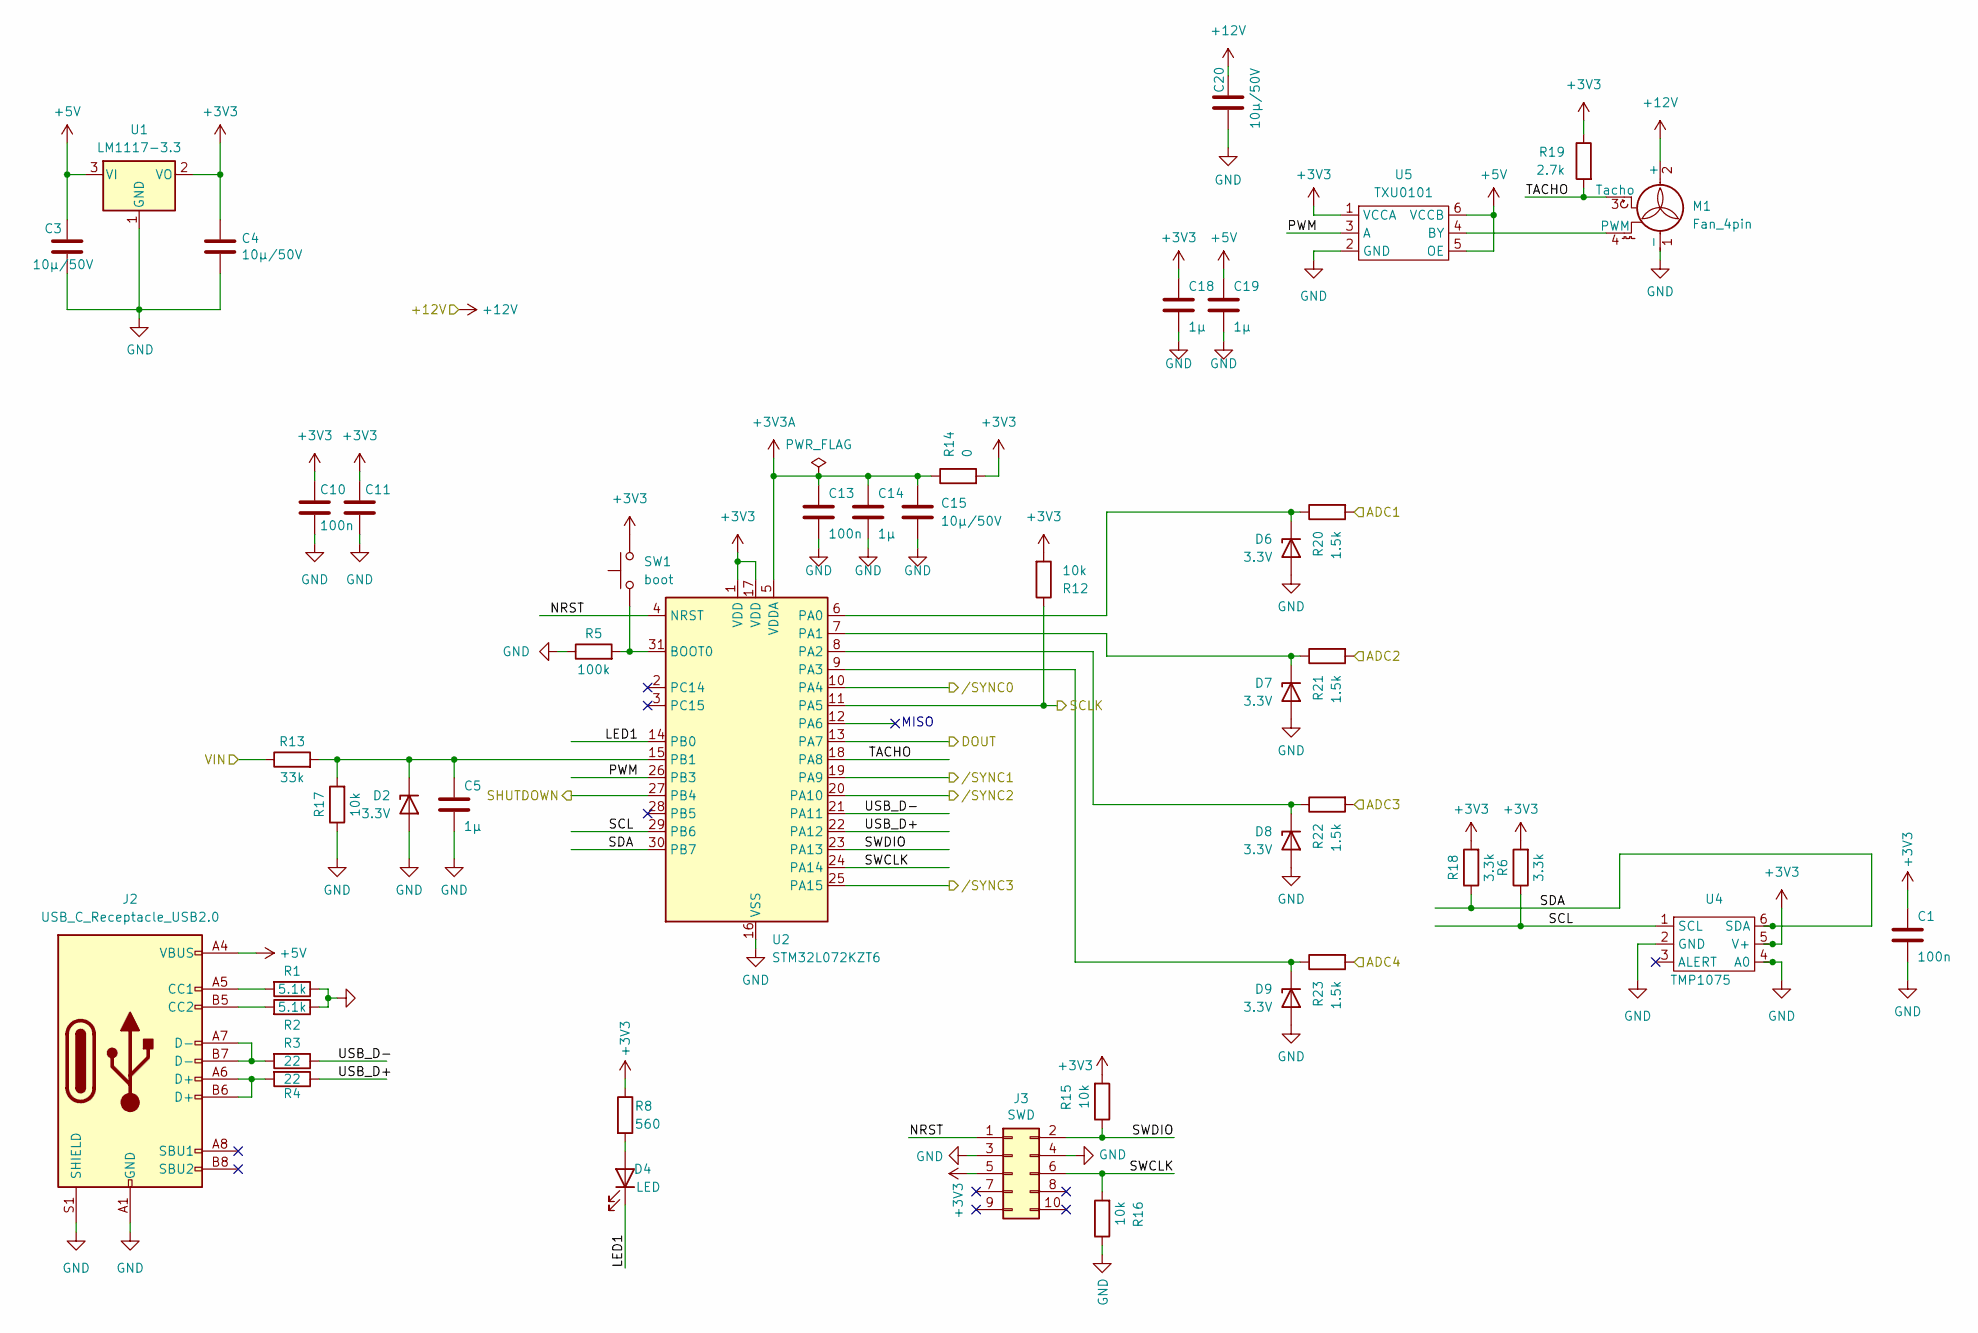
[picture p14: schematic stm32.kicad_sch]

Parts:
C1: 100n; C_0603_1608Metric
C3, C4, C15, C20: 10µ/50V; C_1206_3216Metric
C5, C14, C18, C19: 1µ; C_0805_2012Metric
C10, C11, C13: 100n; C_0805_2012Metric
D2, D6, D7, D8, D9: 3.3V; D_MiniMELF
D4: LED; LED_1206_3216Metric
J2: USB_C_Receptacle_USB2.0; USB_C_Receptacle_GCT_USB4105-xx-A_16P_TopMnt_Horizontal
J3: SWD; PinHeader_IDC_2x05_P1.27mm_Vertical_SMD
M1: Fan_4pin; FanPinHeader_1x04_P2.54mm_Vertical
R1, R2: 5.1k; R_0805_2012Metric
R3, R4: 22; R_0805_2012Metric
R5: 100k; R_0805_2012Metric
R6, R18: 3.3k; R_0805_2012Metric
R8: 560; R_0805_2012Metric
R12, R15, R16, R17: 10k; R_0805_2012Metric
R13: 33k; R_0805_2012Metric
R14: 0; R_0805_2012Metric
R19: 2.7k; R_0805_2012Metric
R20, R21, R22, R23: 1.5k; R_0805_2012Metric
SW1: boot; SW_Push_1P1T_NO_CK_KMR2
U1: LM1117-3.3; SOT-223-3_TabPin2
U2: STM32L072KZT6; LQFP-32_7x7mm_P0.8mm
U4: TMP1075; TMP1075-DRL
U5: TXU0101; SOT-363_SC-70-6

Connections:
+3V3: C1.1, C4.1, C10.1, C11.1, C18.1, J3.5, R6.2, R8.1, R12.2, R14.2, R15.2, R18.2, R19.1, SW1.2, U1.2 (VO), U2.1 (VDD), U2.17 (VDD), U4.5 (V+), U5.1 (VCCA)
+3V3A: C13.1, C14.1, C15.1, R14.1, U2.5 (VDDA)
+5V: C3.1, C19.1, J2.A4 (VBUS), J2.A9 (VBUS), J2.B4 (VBUS), J2.B9 (VBUS), U1.3 (VI), U5.5 (OE), U5.6 (VCCB)
+12V: C20.1, M1.2 (+); also elsewhere on the board
/ADC0: R20.2; also elsewhere on the board
/ADC1: R21.2; also elsewhere on the board
/ADC2: R22.2; also elsewhere on the board
/ADC3: R23.2; also elsewhere on the board
/DIN: U2.13 (PA7); also elsewhere on the board
/SCLK: R12.1, U2.11 (PA5); also elsewhere on the board
/SHUTDOWN: U2.27 (PB4); also elsewhere on the board
/opamps1//SYNC: U2.19 (PA9); also elsewhere on the board
/opamps2//SYNC: U2.20 (PA10); also elsewhere on the board
/opamps3//SYNC: U2.25 (PA15); also elsewhere on the board
/opamps//SYNC: U2.10 (PA4); also elsewhere on the board
/stm32/LED1: D4.1 (K), U2.14 (PB0)
/stm32/NRST: J3.1, U2.4 (NRST)
/stm32/PWM: U2.26 (PB3), U5.3 (A)
/stm32/SCL: R6.1, U2.29 (PB6), U4.1 (SCL)
/stm32/SDA: R18.1, U2.30 (PB7), U4.6 (SDA)
/stm32/SWCLK: J3.6, R16.2, U2.24 (PA14)
/stm32/SWDIO: J3.2, R15.1, U2.23 (PA13)
/stm32/TACHO: M1.3 (Tacho), R19.2, U2.18 (PA8)
/stm32/USB_D+: R4.1, U2.22 (PA12)
/stm32/USB_D-: R3.1, U2.21 (PA11)
/stm32/VIN: R13.1; also elsewhere on the board
GND: C1.2, C3.2, C4.2, C5.2, C10.2, C11.2, C13.2, C14.2, C15.2, C18.2, C19.2, C20.2, D2.2 (A), D6.2 (A), D7.2 (A), D8.2 (A), D9.2 (A), J2.A1 (GND), J2.A12 (GND), J2.B1 (GND), J2.B12 (GND), J2.S1 (SHIELD), J3.3, J3.4, M1.1 (-), R1.1, R2.1, R5.1, R16.1, R17.1, U1.1 (GND), U2.16 (VSS), U2.32 (VSS), U4.2 (GND), U4.4 (A0), U5.2 (GND); also elsewhere on the board
unnamed: C5.1, D2.1 (K), R13.2, R17.2, U2.15 (PB1)
unnamed: D4.2 (A), R8.2
unnamed: D6.1 (K), R20.1, U2.6 (PA0)
unnamed: D7.1 (K), R21.1, U2.7 (PA1)
unnamed: D8.1 (K), R22.1, U2.8 (PA2)
unnamed: D9.1 (K), R23.1, U2.9 (PA3)
unnamed: J2.A5 (CC1), R1.2
unnamed: J2.B5 (CC2), R2.2
unnamed: J2.A6 (D+), J2.B6 (D+), R4.2
unnamed: J2.A7 (D-), J2.B7 (D-), R3.2
unnamed: M1.4 (PWM), U5.4 (BY)
unnamed: R5.2, SW1.1, U2.31 (BOOT0)

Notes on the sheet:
MISO

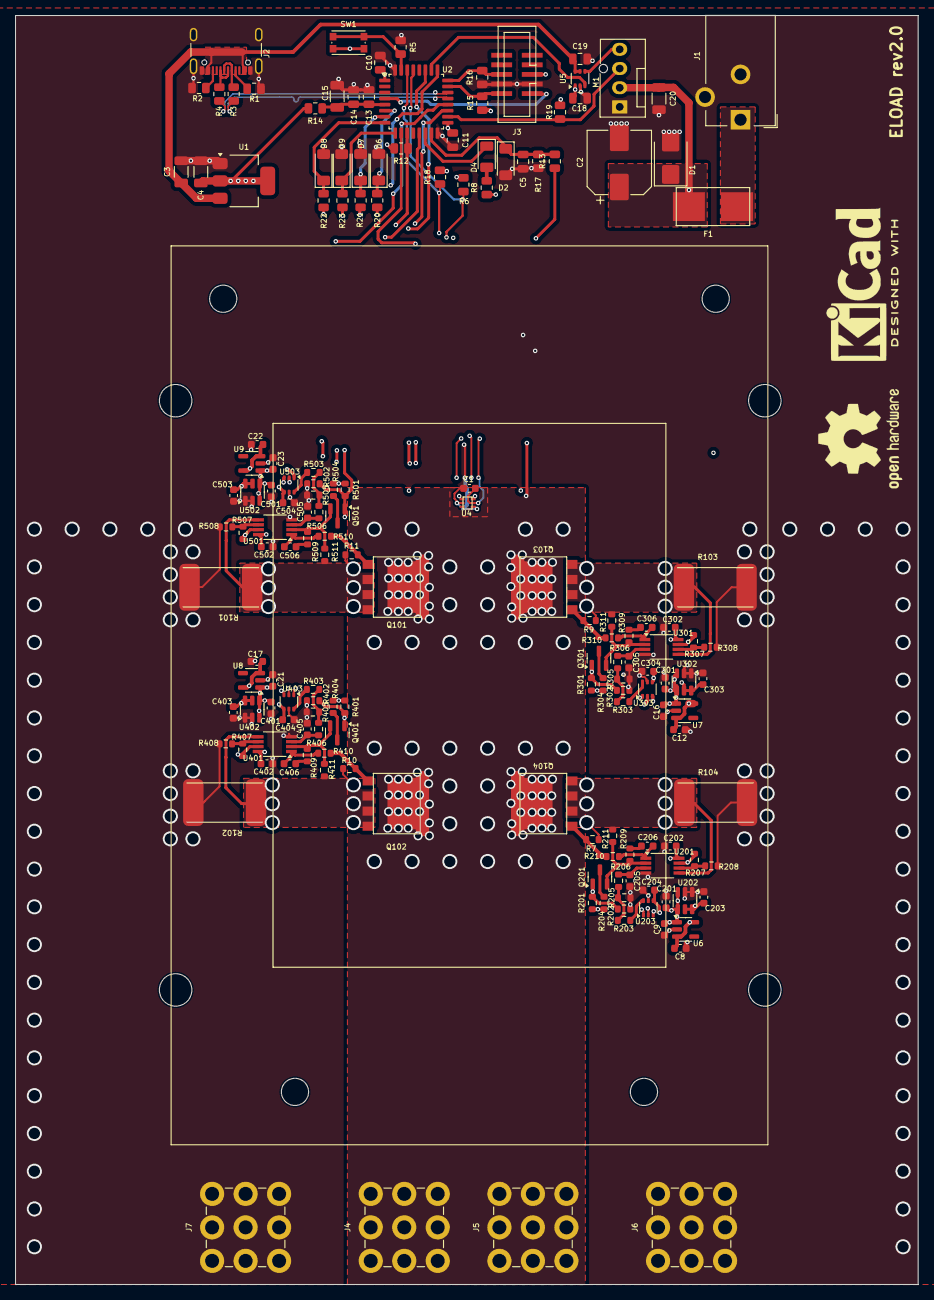
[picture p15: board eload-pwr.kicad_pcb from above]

Board: 4 copper layers, 119.5 x 168.0 mm, 161 parts (0 on the bottom side), 88 nets.

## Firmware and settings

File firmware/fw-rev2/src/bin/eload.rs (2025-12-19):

#![no_std]
#![no_main]

use core::option::Option::Some;
use defmt::{panic, *};
use defmt_rtt as _; // global logger
use embassy_executor::Spawner;
use embassy_stm32::adc::*;
use embassy_stm32::dma::NoDma;
use embassy_stm32::gpio::{Level, Output, OutputType, Speed};
use embassy_stm32::i2c;
use embassy_stm32::i2c::I2c;
use embassy_stm32::spi::Spi;
use embassy_stm32::rcc::*;
use embassy_stm32::time::{khz, Hertz};
use embassy_stm32::timer::simple_pwm::{PwmPin, SimplePwm};
use embassy_stm32::timer::Channel as PWMChannel;
use embassy_stm32::usb::{Driver, Instance};
use embassy_stm32::{adc, bind_interrupts, peripherals, usb, Config};
use embassy_sync::blocking_mutex::raw::ThreadModeRawMutex;
use embassy_sync::channel::Channel;
use embassy_sync::mutex::Mutex;
use embassy_time::{Delay, Timer};

use embassy_stm32::timer::OutputPolarity;
use embassy_usb::class::cdc_acm::{CdcAcmClass, State};
use embassy_usb::driver::EndpointError;
use embassy_usb::Builder;
use futures::future::join3;
use panic_probe as _;

extern crate alloc;
extern crate alloc_cortex_m;

mod protobuf;
use protobuf::coms::{QControl, QRequest, QResponse, QState};
use quick_protobuf::{self, MessageWrite};

use alloc::borrow::Cow;

use alloc_cortex_m::CortexMHeap;

#[global_allocator]
static ALLOCATOR: CortexMHeap = CortexMHeap::empty();

bind_interrupts!(struct Irqs {
    USB => usb::InterruptHandler<peripherals::USB>;
    ADC1_COMP => adc::InterruptHandler<ADC>;
    I2C1 => i2c::EventInterruptHandler<peripherals::I2C1>, i2c::ErrorInterruptHandler<peripherals::I2C1>;
});
use embassy_stm32::peripherals::*;

struct LoadControl {
    sdn: i32,
    pwm: i32,
    dac0: i32,
    dac1: i32,
    dac2: i32,
    dac3: i32,
}

struct LoadState {
    ch0: i32,
    ch1: i32,
    ch2: i32,
    ch3: i32,
    cal: i32,
    v: i32,
    temp: i32,
    sdn: i32,
}

static LOAD_CONTROL: Channel<ThreadModeRawMutex, LoadControl, 1> = Channel::new();

static LOAD_STATE: Mutex<ThreadModeRawMutex, LoadState> = Mutex::new(LoadState {
    ch0: 0,
    ch1: 0,
    ch2: 0,
    ch3: 0,
    cal: 0,
    v: 0,
    temp: 0,
    sdn: 0,
});

#[embassy_executor::main]
async fn main(spawner: Spawner) {
    info!("Hello World!");

    // Initialize the allocator before using it
    let start = cortex_m_rt::heap_start() as usize;
    let size = 1024;
    unsafe { ALLOCATOR.init(start, size) }

    let mut config = Config::default();
    config.rcc.hsi48 = Some(Hsi48Config {
        sync_from_usb: true,
    }); // needed for USB
    config.rcc.mux = ClockSrc::PLL1_R;
    config.rcc.hsi = true;
    config.rcc.pll = Some(Pll {
        source: PllSource::HSI,
        div: PllDiv::DIV3,
        mul: PllMul::MUL6,
    });
    config.rcc.clk48_src = Clk48Src::HSI48;
    config.rcc.apb2_pre = APBPrescaler::DIV1;

    let mut p = embassy_stm32::init(config);

    let driver = Driver::new(p.USB, Irqs, p.PA12, p.PA11);

    // Create embassy-usb Config
    let mut config = embassy_usb::Config::new(0xc0de, 0xcafe);
    config.max_packet_size_0 = 64;
    config.manufacturer = Some("microengineer");
    config.product = Some("E-Load");
    config.serial_number = Some("rev1");

    // Required for windows compatibility.
    // https://developer.nordicsemi.com/nRF_Connect_SDK/doc/1.9.1/kconfig/CONFIG_CDC_ACM_IAD.html#help
    config.device_class = 0xEF;
    config.device_sub_class = 0x02;
    config.device_protocol = 0x01;
    config.composite_with_iads = true;

    // Create embassy-usb DeviceBuilder using the driver and config.
    // It needs some buffers for building the descriptors.
    let mut device_descriptor = [0; 256];
    let mut config_descriptor = [0; 256];
    let mut bos_descriptor = [0; 256];
    let mut control_buf = [0; 64];

    let mut state_usb_ctrl = State::new();

    let mut builder = Builder::new(
        driver,
        config,
        &mut device_descriptor,
        &mut config_descriptor,
        &mut bos_descriptor,
        &mut [], // no msos descriptors
        &mut control_buf,
    );

    let mut class_usb_ctrl = CdcAcmClass::new(&mut builder, &mut state_usb_ctrl, 64);

    // Build the builder.
    let mut usb = builder.build();

    // Run the USB device.
    let usb_fut = usb.run();

    let ch2 = PwmPin::new_ch2(p.PB3, OutputType::PushPull);
    let mut pwm = SimplePwm::new(
        p.TIM2,
        None,
        Some(ch2),
        None,
        None,
        khz(10),
        Default::default(),
    );
    pwm.set_polarity(PWMChannel::Ch2, OutputPolarity::ActiveHigh);
    pwm.set_duty(PWMChannel::Ch2, pwm.get_max_duty());
    pwm.enable(PWMChannel::Ch2);

    let i2c = I2c::new(
        p.I2C1,
        p.PB6,
        p.PB7,
        Irqs,
        NoDma,
        NoDma,
        Hertz(100_000),
        Default::default(),
    );

    let mut spi_config = embassy_stm32::spi::Config::default();
    spi_config.mode = embassy_stm32::spi::MODE_2;
    spi_config.frequency = Hertz(100_000);

    let dac_spi = Spi::new(p.SPI1, p.PA5, p.PA7, p.PA6, p.DMA1_CH3, p.DMA1_CH2, spi_config);

    let dac_cs0 = Output::new(p.PA4, Level::High, Speed::VeryHigh);
    let dac_cs1 = Output::new(p.PA9, Level::High, Speed::VeryHigh);
    let dac_cs2 = Output::new(p.PA10, Level::High, Speed::VeryHigh);
    let dac_cs3 = Output::new(p.PA15, Level::High, Speed::VeryHigh);

    let led1 = Output::new(p.PB0, Level::High, Speed::Low);
    //let led2 = Output::new(p.PB1, Level::High, Speed::Low);

    let eload_sdn = Output::new(p.PB4, Level::High, Speed::Low);

    let mut adc = Adc::new(p.ADC, Irqs, &mut Delay);
    adc.set_sample_time(SampleTime::Cycles160_5);

    let mut vrefint = adc.enable_vref(&mut Delay);

    let adc_fut = async {
        loop {
            let mut samples = [0u16; 6];
            for i in 0..6 {
                let sample = match i {
                    0 => adc.read(&mut p.PA0).await,
                    1 => adc.read(&mut p.PA1).await,
                    2 => adc.read(&mut p.PA2).await,
                    3 => adc.read(&mut p.PA3).await,
                    4 => adc.read(&mut vrefint).await,
                    5 => adc.read(&mut p.PB1).await,
                    _ => 0,
                };
                samples[i] = sample;
            }
            let mut state = LOAD_STATE.lock().await;
            state.ch0 = samples[0] as i32;
            state.ch1 = samples[1] as i32;
            state.ch2 = samples[2] as i32;
            state.ch3 = samples[3] as i32;
            state.cal = samples[4] as i32;
            state.v = samples[5] as i32;
            drop(state);
        }
    };

    unwrap!(spawner.spawn(load_control_channel(led1, eload_sdn, pwm, dac_spi, dac_cs0, dac_cs1, dac_cs2, dac_cs3)));
    unwrap!(spawner.spawn(temp_monitoring_task(i2c)));

    let protobuf_rpc_fut = async {
        loop {
            class_usb_ctrl.wait_connection().await;
            info!("Connected");
            let _ = json_rpc(&mut class_usb_ctrl).await;
            info!("Disconnected");
        }
    };

    let _ = join3(usb_fut, protobuf_rpc_fut, adc_fut).await;
}

#[embassy_executor::task]
async fn temp_monitoring_task(mut i2c: I2c<'static, I2C1>) {
    loop {
        let mut data = [0u8; 2];
        if let Err(e) = i2c.blocking_read(0x48, &mut data) {
            error!("i2c error: {:?}", e);
            continue;
        }

        let mut temp_data = ((data[0] as u16) << 4) | ((data[1] as u16) >> 4);

        if temp_data > 2047 {
            temp_data -= 4096
        }

        info!("read temp: {}", temp_data);

        let mut status = LOAD_STATE.lock().await;
        status.temp = temp_data as i32;
        drop(status);

        Timer::after_millis(5000).await;
    }
}

#[embassy_executor::task]
async fn load_control_channel(
    mut led1: Output<'static>,
    mut sdn: Output<'static>,
    mut pwm: SimplePwm<'static, TIM2>,
    mut dac: Spi<'static, SPI1, DMA1_CH3, DMA1_CH2>,
    mut cs0: Output<'static>,
    mut cs1: Output<'static>,
    mut cs2: Output<'static>,
    mut cs3: Output<'static>,
) {
    let mut buf = [0u8; 3];
    loop {
        let control = LOAD_CONTROL.receive().await;

        match control.sdn {
            0 => {
                sdn.set_low();
                led1.set_low();
            }
            _ => {
                sdn.set_high();
                led1.set_high();
            }
        };

        // set DAC
        let cs = [&mut cs0, &mut cs1, &mut cs2, &mut cs3];
        let dac_val = [control.dac0, control.dac1, control.dac2, control.dac3];

        for i in 0..4 {
            cs[i].set_low();
            let data = (dac_val[i] & 0xffff) << 6;

            buf[0] = ((data & 0x00ff0000) >> 16) as u8;
            buf[1] = ((data & 0x0000ff00) >> 8) as u8;
            buf[2] =  (data & 0x000000ff) as u8;

            let _ = dac.write(&mut buf).await;

            cs[i].set_high();
        }


        // set PWM
        pwm.set_duty(
            PWMChannel::Ch2,
            (pwm.get_max_duty() as u32 * control.pwm as u32 / 100) as u16,
        );
    }
}
struct Disconnected {}

impl From<EndpointError> for Disconnected {
    fn from(val: EndpointError) -> Self {
        match val {
            EndpointError::BufferOverflow => panic!("Buffer overflow"),
            EndpointError::Disabled => Disconnected {},
        }
    }
}

enum Errors {
    None = 0,
    InvalidCommand = 1,
    ErrorDeserializingRequest = 2,
    ErrorSerializingResponse = 3,
    ErrorDeserializingRequestData = 4,
    ErrorSerializingResponseData = 5,
}

impl Errors {
    fn to_string(error: &Errors) -> &'static str {
        match error {
            Errors::InvalidCommand => "invalid command",
            Errors::ErrorDeserializingRequest => "error deserializing request",
            Errors::ErrorSerializingResponse => "error serializing response",
            Errors::ErrorDeserializingRequestData => "error deserializing request data",
            Errors::ErrorSerializingResponseData => "error serializing response data",
            _ => "unknown error",
        }
    }
}
enum Commands {
    NOP = 0,
    Control = 1,
    Status = 2,
}

impl Commands {
    fn from_i32(value: i32) -> Option<Commands> {
        match value {
            0 => Some(Commands::NOP),
            1 => Some(Commands::Control),
            2 => Some(Commands::Status),
            _ => None,
        }
    }
}

impl QResponse<'_> {
    fn default() -> QResponse<'static> {
        QResponse {
            id: 0,
            error: 0,
            data: Cow::Borrowed(&[0u8]),
        }
    }
}

// The response_bytes should be a mutable slice of u8, not a slice of a mutable slice.
async fn process_request<'a>(
    request: &QRequest<'_>,
    response: &mut QResponse<'_>,
) -> Result<usize, Errors> {
    let mut response_data = [0u8; 32];
    let mut response_len = 0;
    let error = Errors::None as i32;

    let op = Commands::from_i32(request.op);
    if op.is_none() {
        return Err(Errors::InvalidCommand);
    }

    match op.unwrap() {
        Commands::NOP => {
            // nop
        }
        Commands::Control => {
            let cmd: QControl = quick_protobuf::deserialize_from_slice(&request.data)
                .map_err(|_| Errors::ErrorDeserializingRequestData)?;

            info!(
                "receiving ctrl sdn: {}, pwm: {}, dac0: {}, dac1: {}, dac2: {}, dac3: {}",
                cmd.sdn, cmd.pwm, cmd.dac0, cmd.dac1, cmd.dac2, cmd.dac3
            );

            let control = LoadControl {
                sdn: cmd.sdn,
                pwm: cmd.pwm,
                dac0: cmd.dac0,
                dac1: cmd.dac1,
                dac2: cmd.dac2,
                dac3: cmd.dac3,
            };
            LOAD_CONTROL.send(control).await;
        }
        Commands::Status => {
            let state = LOAD_STATE.lock().await;
            let qstate = QState {
                ch0: state.ch0,
                ch1: state.ch1,
                ch2: state.ch2,
                ch3: state.ch3,
                cal: state.cal,
                v: state.v,
                temp: state.temp,
                sdn: state.sdn,
            };
            drop(state);

            info!("sending state - ch0: {}, ch1: {}, ch2: {}, ch3: {}, cal: {}, v: {}, temp: {}, sdn: {}", qstate.ch0, qstate.ch1, qstate.ch2, qstate.ch3, qstate.cal, qstate.v, qstate.temp, qstate.sdn);

            response_len = qstate.get_size() + 1 /* varint */;
            quick_protobuf::serialize_into_slice(&qstate, &mut response_data[..])
                .map_err(|_| Errors::ErrorSerializingResponseData)?;
        }
    };

    response.id = request.id;
    response.error = error;
    response.data = Cow::Owned(response_data[..response_len].to_vec());
    debug!(
        "response.id: {}, response.error:{}, response.data: {:?}",
        response.id,
        response.error,
        response_data[..response_len]
    );
    Ok(response_len)
}

async fn json_rpc<'d, T: Instance + 'd>(
    class: &mut CdcAcmClass<'d, Driver<'d, T>>,
) -> Result<(), Disconnected> {
    let mut request_bytes = [0u8; 64];
    let mut response_bytes = [0u8; 64];

    loop {
        let n = class.read_packet(&mut request_bytes).await?;

        let mut response = QResponse::default();

        let request = match quick_protobuf::deserialize_from_slice(&request_bytes[..n]) {
            Ok(req) => Some(req),
            Err(_) => {
                error!("{}", Errors::to_string(&Errors::ErrorDeserializingRequest));
                response = QResponse::default();
                response.error = Errors::ErrorDeserializingRequest as i32;
                None
            }
        };

        // if request is some then we can process the request
        if request.is_some() {
            if let Err(e) = process_request(&request.unwrap(), &mut response).await {
                error!("{}", Errors::to_string(&e));
                response = QResponse::default();
                response.error = e as i32;
            }
        }

        let serialized_len = response.get_size() + 1 /* varint */;
        if let Err(_) = quick_protobuf::serialize_into_slice(&response, &mut response_bytes) {
            error!("{}", Errors::to_string(&Errors::ErrorSerializingResponse));
            continue;
        }

        class
            .write_packet(&response_bytes[..serialized_len])
            .await?;
    }
}

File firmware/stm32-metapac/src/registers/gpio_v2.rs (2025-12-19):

                    use crate::metadata::ir::*;
                    pub(crate) static REGISTERS: IR = IR {
    blocks: &[
        Block {
            name: "Gpio",
            extends: None,
            description: Some(
                "General-purpose I/Os",
            ),
            items: &[
                BlockItem {
                    name: "moder",
                    description: Some(
                        "GPIO port mode register",
                    ),
                    array: None,
                    byte_offset: 0,
                    inner: BlockItemInner::Register(
                        Register {
                            access: Access::ReadWrite,
                            bit_size: 32,
                            fieldset: Some(
                                "Moder",
                            ),
                        },
                    ),
                },
                BlockItem {
                    name: "otyper",
                    description: Some(
                        "GPIO port output type register",
                    ),
                    array: None,
                    byte_offset: 4,
                    inner: BlockItemInner::Register(
                        Register {
                            access: Access::ReadWrite,
                            bit_size: 32,
                            fieldset: Some(
                                "Otyper",
                            ),
                        },
                    ),
                },
                BlockItem {
                    name: "ospeedr",
                    description: Some(
                        "GPIO port output speed register",
                    ),
                    array: None,
                    byte_offset: 8,
                    inner: BlockItemInner::Register(
                        Register {
                            access: Access::ReadWrite,
                            bit_size: 32,
                            fieldset: Some(
                                "Ospeedr",
                            ),
                        },
                    ),
                },
                BlockItem {
                    name: "pupdr",
                    description: Some(
                        "GPIO port pull-up/pull-down register",
                    ),
                    array: None,
                    byte_offset: 12,
                    inner: BlockItemInner::Register(
                        Register {
                            access: Access::ReadWrite,
                            bit_size: 32,
                            fieldset: Some(
                                "Pupdr",
                            ),
                        },
                    ),
                },
                BlockItem {
                    name: "idr",
                    description: Some(
                        "GPIO port input data register",
                    ),
                    array: None,
                    byte_offset: 16,
                    inner: BlockItemInner::Register(
                        Register {
                            access: Access::Read,
                            bit_size: 32,
                            fieldset: Some(
                                "Idr",
                            ),
                        },
                    ),
                },
                BlockItem {
                    name: "odr",
                    description: Some(
                        "GPIO port output data register",
                    ),
                    array: None,
                    byte_offset: 20,
                    inner: BlockItemInner::Register(
                        Register {
                            access: Access::ReadWrite,
                            bit_size: 32,
                            fieldset: Some(
                                "Odr",
                            ),
                        },
                    ),
                },
                BlockItem {
                    name: "bsrr",
                    description: Some(
                        "GPIO port bit set/reset register",
                    ),
                    array: None,
                    byte_offset: 24,
                    inner: BlockItemInner::Register(
                        Register {
                            access: Access::Write,
                            bit_size: 32,
                            fieldset: Some(
                                "Bsrr",
                            ),
                        },
                    ),
                },
                BlockItem {
                    name: "lckr",
                    description: Some(
                        "GPIO port configuration lock register",
                    ),
                    array: None,
                    byte_offset: 28,
                    inner: BlockItemInner::Register(
                        Register {
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

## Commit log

2025-12-19 restructured directories
    [digikey.csv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]
2025-12-19 set 22R to 0R (fix for adc)
    [eload-pwr.kicad_pcb, stm32.kicad_sch]
2025-12-19 calculate power
